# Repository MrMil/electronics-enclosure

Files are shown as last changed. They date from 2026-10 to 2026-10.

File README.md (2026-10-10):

# electronics-enclosure

Parametric 3D-printed enclosures for mains-powered LED controllers. Each enclosure houses a
power supply, a C14 inlet, perfboards and connectors, and is generated from a YAML file of
measurements into ready-to-slice STLs: an open base and a tool-free sliding lid.

<!-- META-DOCS:BEGIN -->
## Documentation

The design of this project, and the reasoning behind it, lives in [`docs/`](docs/README.md) — a
recursive tree that mirrors the system part by part, down to individual behaviours, with every
decision recorded alongside the reason it was made. Start at the hub and navigate down.

These docs are written for LLM coding agents. Design changes are documented in the same commit that
makes them; see [`docs/CONVENTIONS.md`](docs/CONVENTIONS.md).
<!-- META-DOCS:END -->

## Enclosures

| Name | Power supply | Contents | Prints |
|---|---|---|---|
| [`20W`](enclosures/20W/BOM.md) | S-20-5 (5 V 4 A) | C14, 1 perfboard, 2 LED exits in the floor | base + lid on one A1 plate |
| [`100W`](enclosures/100W/BOM.md) | S-100-5 (5 V 20 A) | C14, 1 perfboard, 4 LED exits | base and lid separately |
| [`100W-rj45`](enclosures/100W-rj45/BOM.md) | S-100-5 | as 100W plus an RJ45 bulkhead | base and lid separately |
| [`100W-leds-on-floor`](enclosures/100W-leds-on-floor/BOM.md) | S-100-5 | as 100W, LED exits in the floor | base and lid separately |
| [`100W-masterbox`](enclosures/100W-masterbox/BOM.md) | S-100-5 | C14, ESP32 board, MAX485 board, 3 RJ45, 4 LED exits | base and lid separately, fills the A1 bed |
| [`100W-power-only`](enclosures/100W-power-only/BOM.md) | S-100-5 | C14, 2 XT60 pigtail outputs, no perfboard | base and lid separately |

Each enclosure's `BOM.md` shows renders of it (empty base, base with parts, closed) and lists its
printed parts, bolts and nuts, where supports may be needed, and what to check before printing.

| | Base, no lid | Base with parts | Closed |
|---|---|---|---|
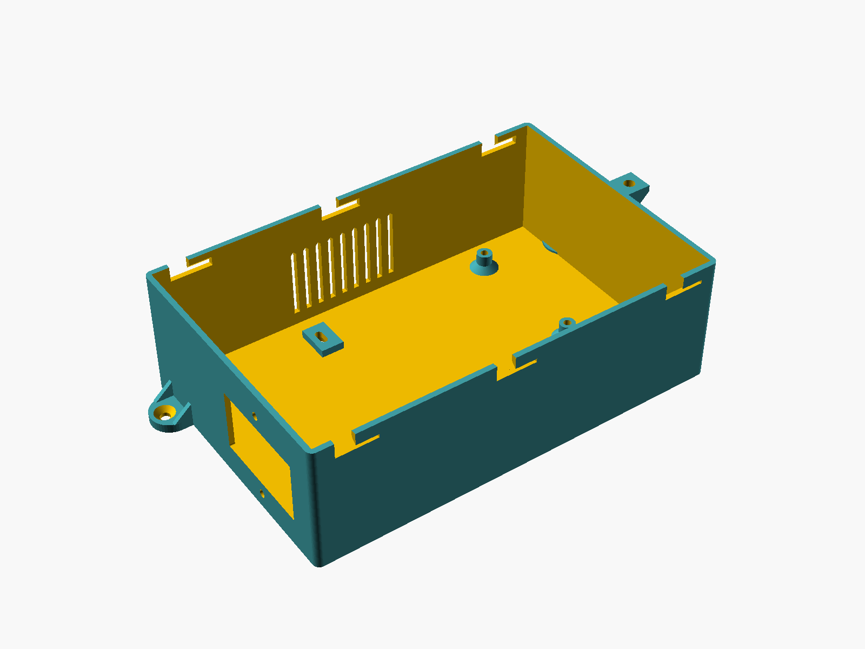
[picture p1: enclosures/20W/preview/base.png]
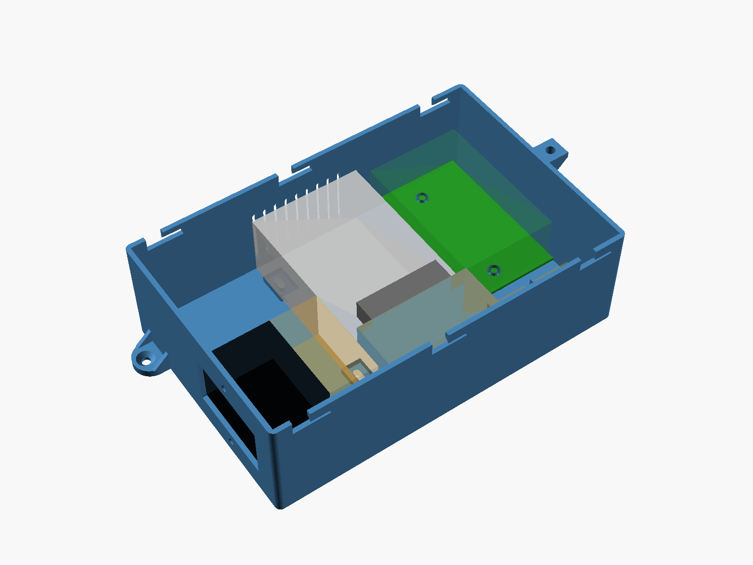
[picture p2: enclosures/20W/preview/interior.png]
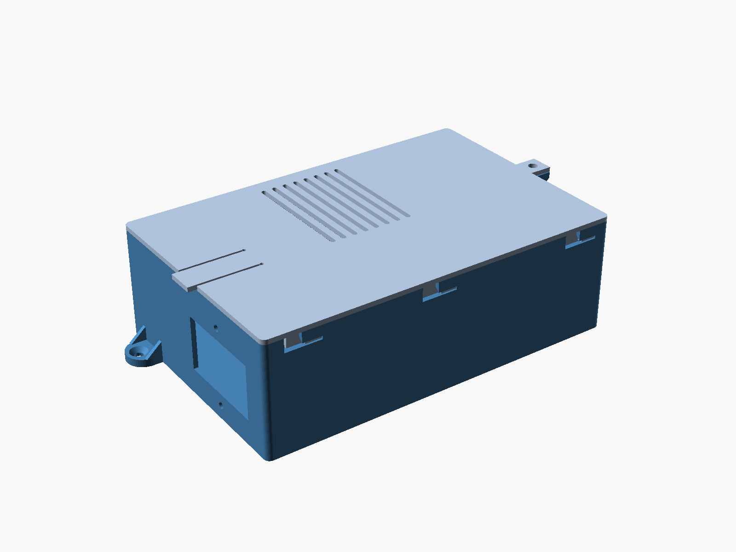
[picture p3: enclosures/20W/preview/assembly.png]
| **20W** |  |  |  |
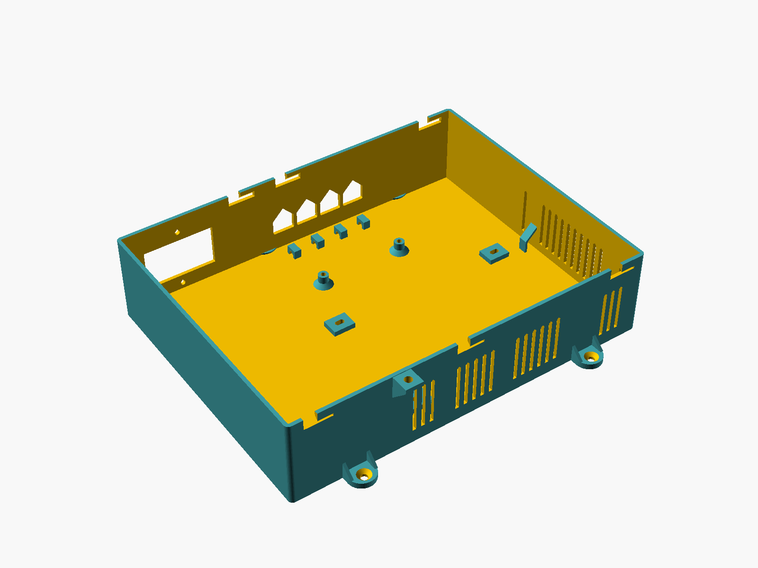
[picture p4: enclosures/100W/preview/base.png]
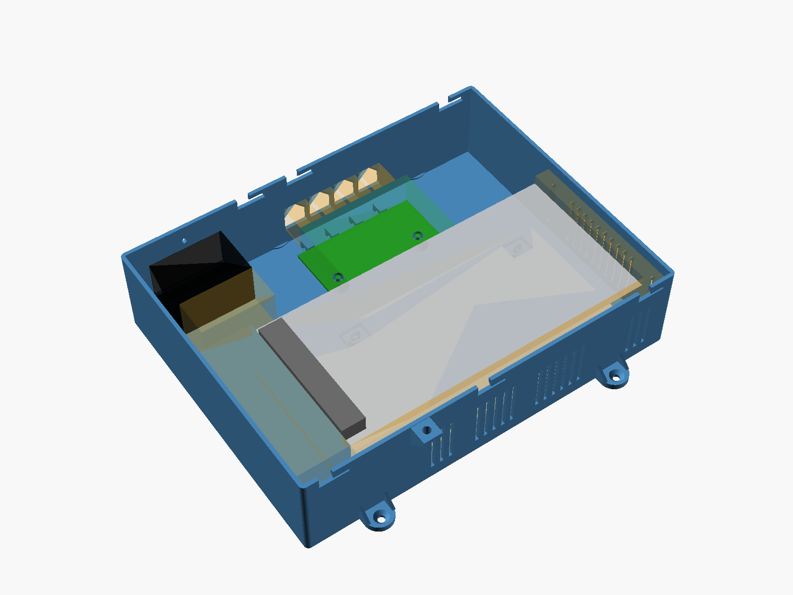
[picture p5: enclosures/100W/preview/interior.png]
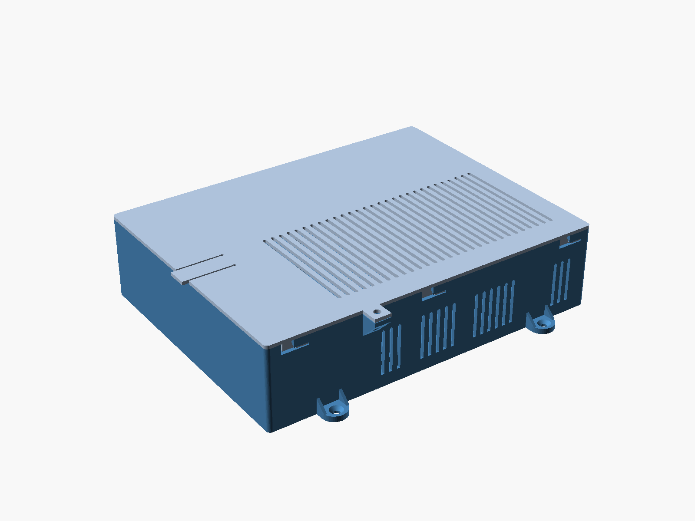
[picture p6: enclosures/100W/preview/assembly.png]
| **100W** |  |  |  |
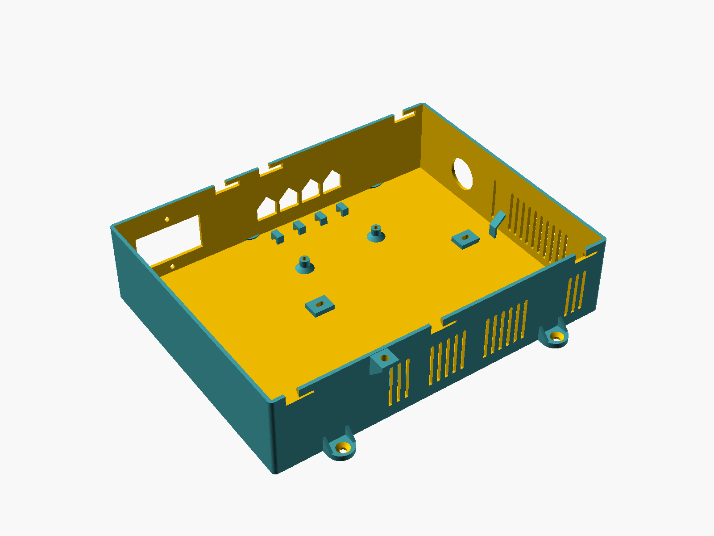
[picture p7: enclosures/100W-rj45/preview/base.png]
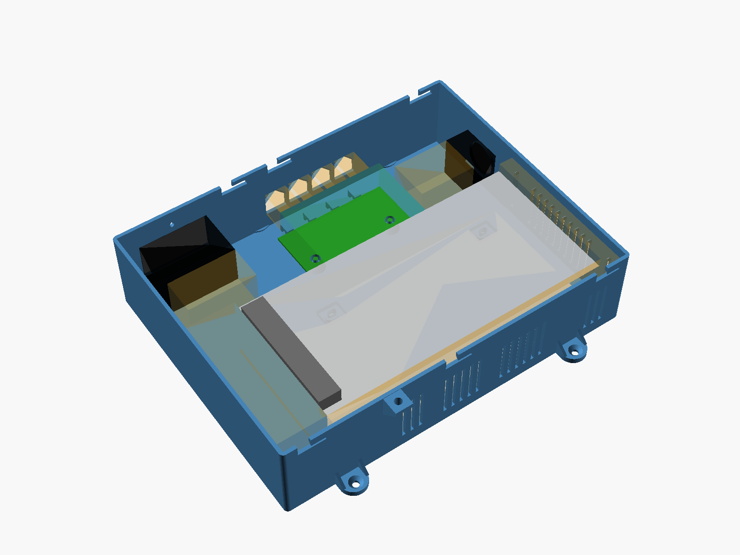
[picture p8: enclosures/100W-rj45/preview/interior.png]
| **100W-rj45** |  |  |  |
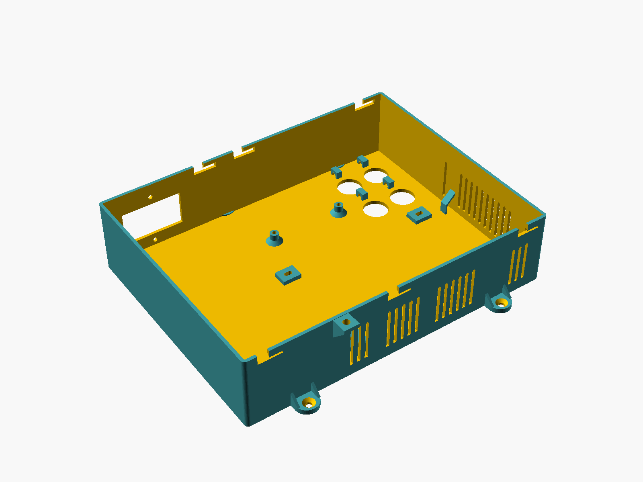
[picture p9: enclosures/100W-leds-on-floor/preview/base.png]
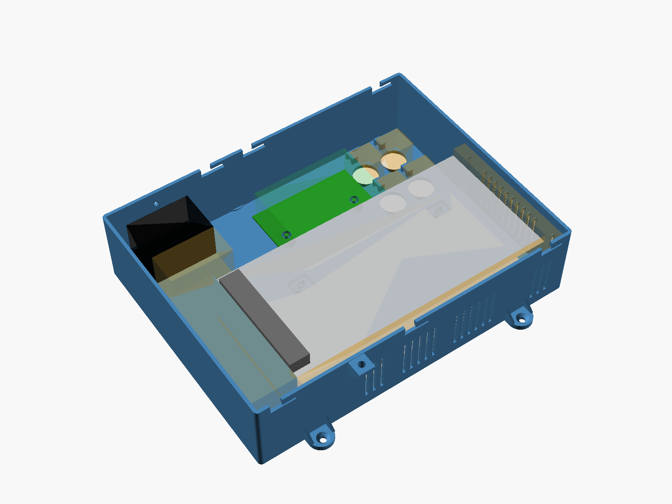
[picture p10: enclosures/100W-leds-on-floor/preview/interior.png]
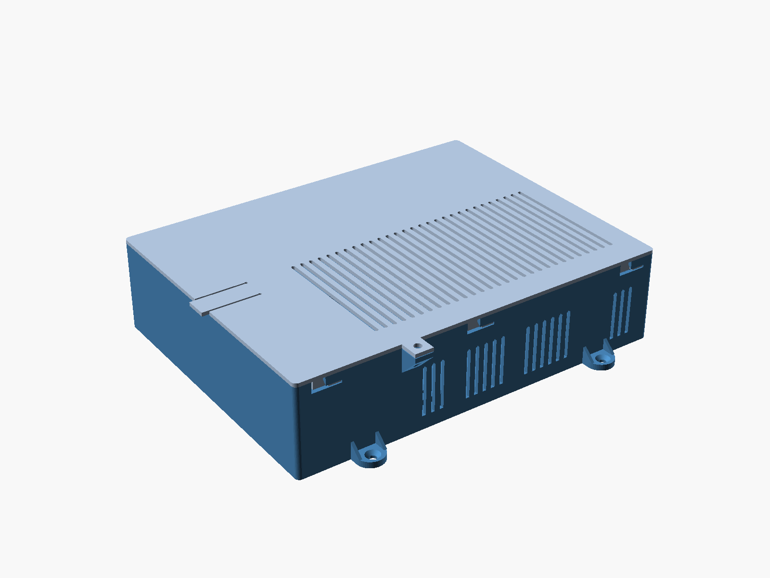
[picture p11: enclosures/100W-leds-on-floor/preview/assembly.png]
| **100W-leds-on-floor** |  |  |  |
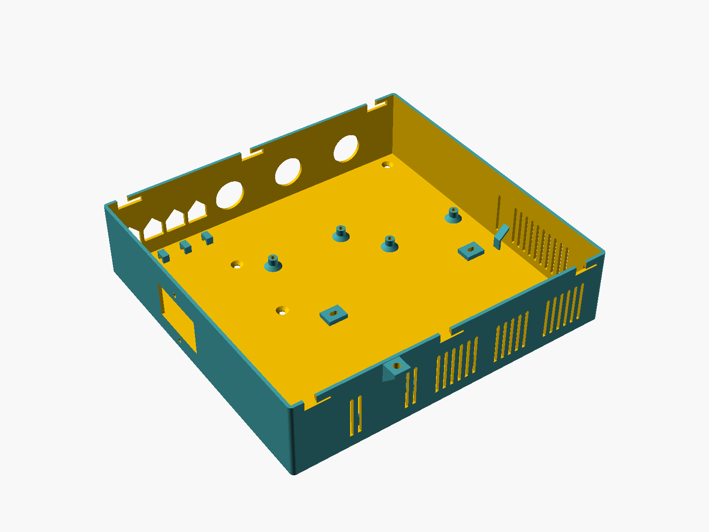
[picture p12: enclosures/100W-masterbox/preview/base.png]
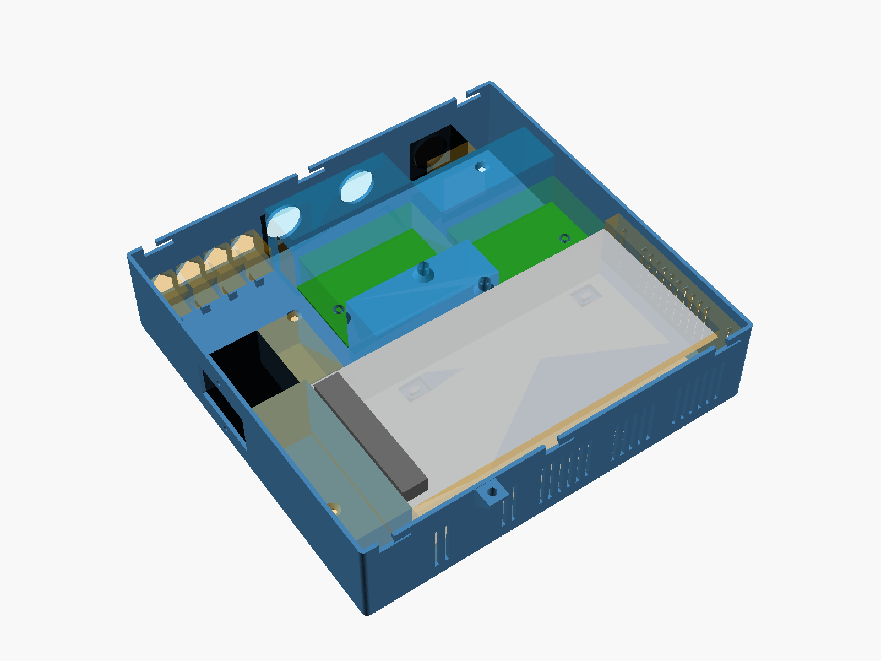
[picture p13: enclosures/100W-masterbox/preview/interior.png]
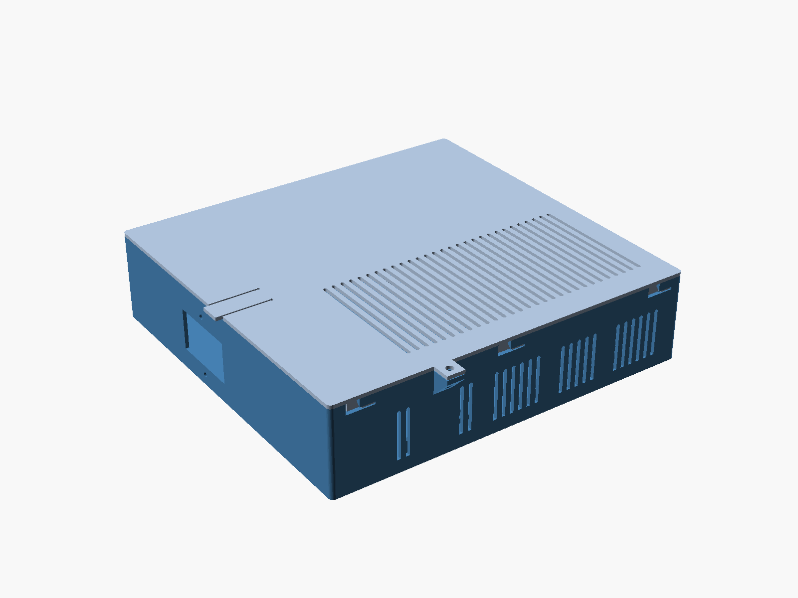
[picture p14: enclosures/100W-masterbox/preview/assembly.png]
| **100W-masterbox** |  |  |  |
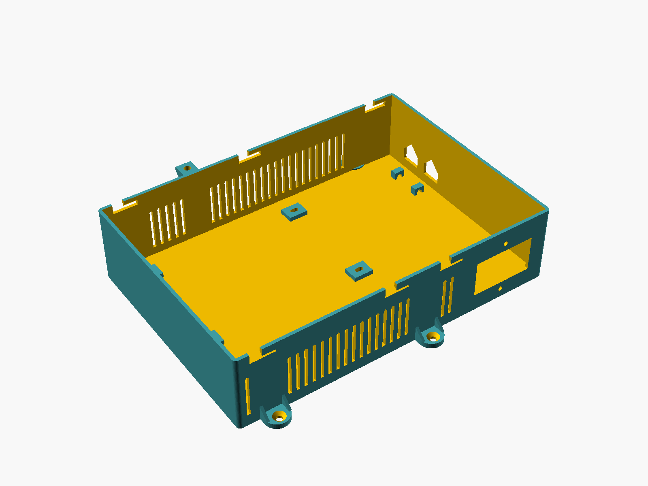
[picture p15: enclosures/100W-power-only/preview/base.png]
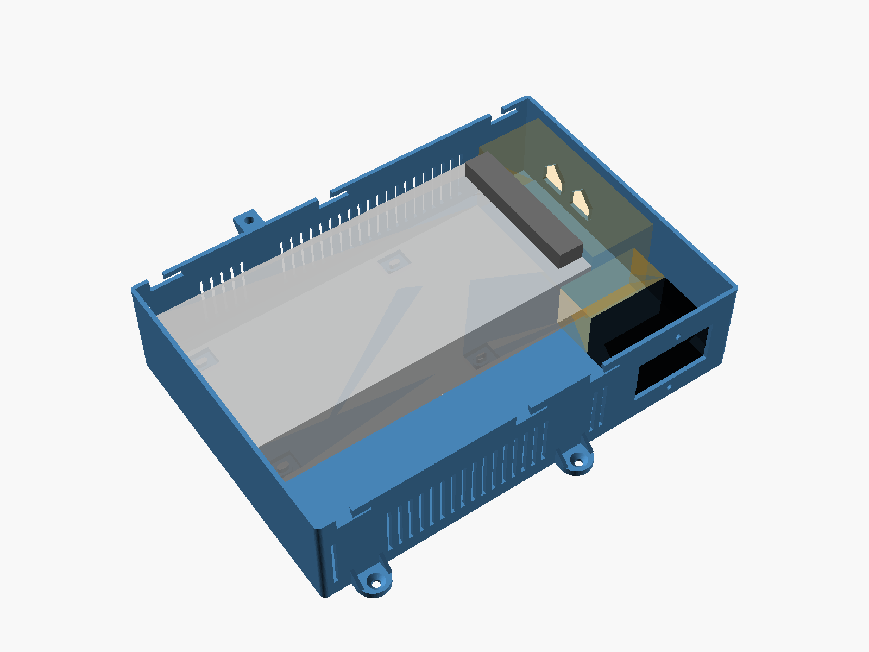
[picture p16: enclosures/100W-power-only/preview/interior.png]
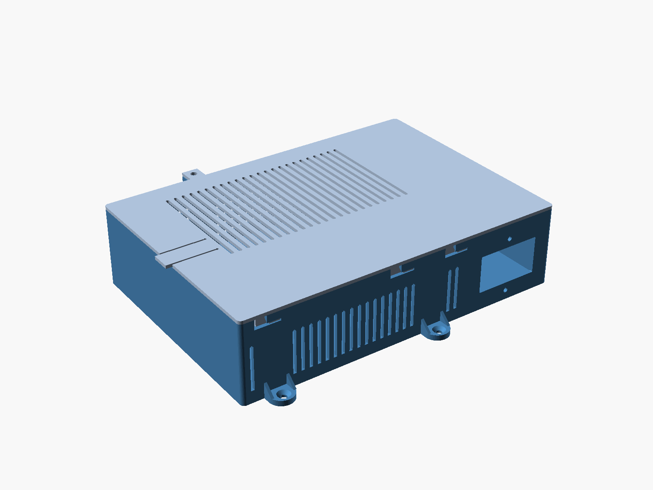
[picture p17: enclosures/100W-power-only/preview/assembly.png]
| **100W-power-only** |  |  |  |

## Quick start

```bash
python3 -m venv .venv && .venv/bin/pip install -r requirements.txt
```

```bash
brew install --cask openscad@snapshot
```

```bash
.venv/bin/python build.py 100W
```

Outputs land in `enclosures/<name>/`:

- `stl/<name>-enclosure-base.stl`, `stl/<name>-enclosure-lid.stl` — already in print orientation;
  `stl/<name>-enclosure-plate.stl` too when both fit on one bed.
- `preview/*.png` — the box closed, open with its parts as coloured blocks, and empty.
- `BOM.md` — hardware, print notes, board-drilling positions for floor wire exits, checks.

`--check` validates a layout without rendering; with no name, every enclosure is built.
`--coupon jst-sm-3pin` writes a small test plate for trying a connector through its slot.

## How a box is put together

- **Power supply** bolts up through the floor into its own M3 threads.
- **Mains and low voltage never cross:** the C14 sits on the supply's AC side; low-voltage wires
  stay on the DC side or run through printed wire loops around the supply's far end.
- **Lid:** drops in 10 mm off-centre, slides shut and clicks. Lift the tab at the edge to open.
  A zip tie through the lock lugs keeps it shut.
- **Hardware:** M3 socket-head bolts and M3 hex nuts only, no heat-set inserts.
- **Print in PETG or ASA**, not PLA: the supply runs warm.

## Layout

| Path | What |
|---|---|
| `enclosures/<name>/enclosure.yaml` | one enclosure: interior size and where each part goes |
| `components/<kind>/<part>.yaml` | measured parts (PSUs, perfboard, panel connectors, pass-throughs), reused across enclosures |
| `config/defaults.yaml` | house style: walls, M3 hardware, lid, vents, mounting, printer bed |
| `enclosure_builder/` | Python: merge, layout, validation, BOM, OpenSCAD driver |
| `scad/enclosure.scad` | geometry library |
| `test-prints/` | small test-fit pieces |
| `docs/` | design decisions and their reasons |

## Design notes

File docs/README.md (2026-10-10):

# Documentation Hub

**Audience: LLM coding agents working in this repository. Not human onboarding material.**
Optimise for a reader with no memory of previous sessions, who can read files fast, and who needs
to know *why* the code is the way it is before changing it.

This tree mirrors the system as a recursive hub-and-spoke: every directory is a part of the system,
its `README.md` indexes what is inside it, and the nesting goes as deep as the system does. Each
page explains its piece and records the reason behind every choice made there. The code is the
source of truth for what happens. These docs are the source of truth for why.

## How to use this tree

1. Start here and navigate down, one index at a time, to the page covering what you are about to change. Never guess paths.
2. **Read every `README.md` on the way down.** Decisions recorded at a level apply to everything beneath it. The reason a leaf behaves as it does may be recorded two levels up.
3. Before finishing work, run the documentation pass in [CONVENTIONS.md](CONVENTIONS.md#the-documentation-pass).

## Design

The system turns measurements of specific hardware into printable enclosures. Each enclosure is a
named directory under `enclosures/` holding its `enclosure.yaml` and the generated STLs. Every
enclosure houses a power supply.

### Decisions

- **The owner's requirements are the root constraints.** Every
  enclosure: houses a PSU and keeps it ventilated; holds a perfboard by its holes (2 for the first
  board, 4 for most); has a C13-cord inlet (a C14 module) in a side wall; has wire exits for LED
  strips (a power-only box, with the PSU's outputs on connectors instead of a board, is the owner's
  call per enclosure: `100W-power-only`, 2026-10-10); may have an RJ45 bulkhead; has a lid that cannot come undone but opens repeatedly
  without tools, bolts or nuts (hardware is fine for assembly, not for opening); leaves room for
  the wires and cables every part has; has parametric holes for fixing it in place; prints with minimal supports; uses as few non-printed
  parts as possible, one bolt size, and no threaded inserts — bolts through printed walls into
  nuts are preferred. Agents must not trade any of these away without asking the owner.
- **One bolt size: M3 socket head everywhere.** The owner asked for a single small bolt size and
  the S-100-5 PSU's own mounting holes are M3, so M3 is the size that needs no adapter. The only
  non-M3 fasteners are the screws that fix the enclosure to its surface (owner's choice, a
  parameter) and the RJ45 coupler's own nut.
- **No threaded inserts, no tapping plastic.** Every M3 joint ends in a metal thread: the PSU's
  own threads, or a hex nut held in a printed pocket or slot. Owner preference; it also means
  threads never wear out with repeated opening.
- **Geometry adapts to standard bolt lengths, not the reverse.** Printed heights (PSU pads,
  standoffs, nut-slot depth) are computed from a chosen standard M3 length, because printed
  dimensions are free and bolt lengths are discrete. The BOM then lists only lengths you can buy.
- **Everything prints without supports**, by fixed print orientation (base floor-down, lid
  top-down) plus the tricks in [enclosure/printability.md](enclosure/printability.md). Owner
  requirement.
- **Find dimensions in manufacturer documentation first; the owner verifies.** The owner would
  rather check a few numbers than take many caliper measurements (and finds some, like flange
  overhangs, hard to measure). Component files record `source:` and `verified: true | datasheet |
  false`. `datasheet` values are listed in the BOM under "Check before printing" with the one
  measurement that confirms them; `false` (guessed) values are build warnings. A guessed number
  can therefore never silently become "known".
- **Units are millimetres; one coordinate frame everywhere** — defined in
  [parameters/README.md](parameters/README.md).
- **Print in PETG or ASA, not PLA.** The PSU case runs warm at full load, and PLA creeps under the
  bolted PSU pads over time. Recorded in every generated BOM.

### YAML → Python → OpenSCAD

**Why.** The person (or agent) creating an enclosure writes measurements; YAML is the easiest
format to write and diff. Layout logic (deriving heights from bolt lengths, generating vents that
avoid other features, checking collisions, writing a BOM) is awkward in OpenSCAD's language and
easy in Python. OpenSCAD is the standard tool in 3D printing for parametric solids, and the
generated `.scad` files can be opened in its GUI for inspection.
**Rejected.** CadQuery: no wheels for the Python in use (3.14) and a heavy OCC dependency. Pure
OpenSCAD with the Customizer: no validation, no BOM, and parameters would live in a format nobody
else reads.
**Constrains.** The SCAD library is geometry-only and knows nothing about specific components;
all component knowledge lives in Python and the component YAML files. Requires an OpenSCAD
snapshot with the manifold backend (2021.01 stable is far too slow for the vent patterns).

## Areas

- [`parameters/`](parameters/README.md) — the YAML inputs: defaults, component library, enclosure definitions, coordinate frame.
- [`enclosure/`](enclosure/README.md) — the printed object: shell, lid closure, PSU and perfboard mounts, wall openings, ventilation, mounting, printability.
- [`pipeline/`](pipeline/README.md) — `build.py`: layout model, validation, SCAD/BOM output and rendering.
- [`enclosures/`](enclosures/README.md) — the concrete, named enclosures and what is still unmeasured in each.

## Files

- [CONVENTIONS.md](CONVENTIONS.md) — the rules for writing and maintaining these docs. Read before adding anything here.

## Invariants

These hold at every depth. If you find one broken, fix it before continuing your task.

- Every directory under `docs/` contains a `README.md` listing every subdirectory and every `.md` file beside it, each with a one-line description.
- Every page and every index links to its parent, carries its breadcrumb path, and links to at least one related page.
- No statement of a design choice appears anywhere in this tree without its reason.
- Every decision is recorded at the lowest level that contains everything it governs.
- No code change ships without the corresponding documentation change in the same commit.

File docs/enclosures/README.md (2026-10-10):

# Enclosures

Path: [docs](../README.md) › **enclosures**
Parent: [../README.md](../README.md)

**Covers:** the concrete, named enclosures in `enclosures/`, the layout decisions specific to
each, and which of their parts are still unmeasured.
**Code:** `enclosures/*/enclosure.yaml`

## Design

### Decisions

- **One page per enclosure, named after it.** Layout choices (which wall the inlet is on, where
  mains and low voltage are separated) belong to one enclosure and must not leak into the feature
  pages, which apply to all of them.
- **LED exits go in a wall unless the owner asks for the floor** (owner, 2026-10-08). Floor
  exits need the mounting board drilled, so they are the owner's call per enclosure: `20W` and
  `100W-leds-on-floor` have them; `100W`, `100W-rj45` and `100W-masterbox` keep theirs in the
  back wall.
  **Changed 2026-10-08:** previously "100W boxes never use the floor", from the owner moving the
  masterbox's exits back into a wall; the owner then asked for a 100W variant with floor exits.
- **Variants of one layout share a page and use `extends`** (`100W-rj45` and
  `100W-leds-on-floor` extend `100W`), so their layout reasoning is written once.
- **Enclosure names are the owner's**, after the PSU's power (`100W`), with a `-<variant>`
  suffix for variants (`100W-rj45`). A new revision with incompatible hole positions gets a new
  name rather than silently replacing STLs someone may already have printed.
  **Changed 2026-10-08:** previously agent-chosen descriptive names (`led-controller-1`).

## Contents

### Pages

- [`20w.md`](20w.md) — `20W`: S-20-5 PSU facing the front, inlet left, perfboard beside it, two round JST-SM LED holes in the floor.
- [`100w-masterbox.md`](100w-masterbox.md) — `100W-masterbox`: bed-filling S-100-5 box, ESP32 board + MAX485 board with side clearance, three RJ45s, four back-wall LED exits.
- [`100w-power-only.md`](100w-power-only.md) — `100W-power-only`: S-100-5 with terminals to the right, C14 in the front wall (sharing it with the lid-lock slots), two XT60 pigtail outputs through the right wall beside the DC terminals; no perfboard.
- [`100w.md`](100w.md) — `100W`, `100W-rj45` and `100W-leds-on-floor`: S-100-5 PSU, DIKAVS perfboard, C14 inlet, four JST-SM LED exits (back wall, or floor), optional RJ45.

## Related

- [../parameters/enclosure_definition.md](../parameters/enclosure_definition.md) — how to write a new one.

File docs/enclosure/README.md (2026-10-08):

# Enclosure

Path: [docs](../README.md) › **enclosure**
Parent: [../README.md](../README.md)

**Covers:** the printed object — two parts, base and lid — and every feature on them. Each page
covers one feature end to end: its component YAML (if any), its placement in Python, and its
geometry in SCAD.
**Code:** `scad/enclosure.scad`, `enclosure_builder/layout.py`, `components/`

## Design

### Decisions

- **Two printed parts: an open-top base and a flat lid.** All components mount to the floor and
  walls of the base, so the lid carries nothing and can be removed without disturbing wiring.
  Rejected: a clamshell split at mid-height — panel parts would straddle the seam, and the PSU
  would have to be mounted to a part that is lifted off.
- **Base prints floor-down, lid prints top-face-down.** Both put their largest flat face on the
  bed, which leaves every hole either vertical or in a vertical wall — the two cases that print
  without supports. See [printability.md](printability.md).
- **The SCAD library only knows generic primitives** (wall rects/rounds/slots, floor bolts,
  standoffs, pads, lock slots and tongues, tabs, tie anchors, lid slots, ghosts). Every feature page below
  describes the Python function that emits them. See the root
  [YAML → Python → OpenSCAD](../README.md#yaml--python--openscad) decision.
- **Every part declares the space its wires need, as a `wiring` keep-out.** PSU terminals,
  panel-part cables and wire exits all get one; wiring zones may meet each other (that is where
  connections are made) but nothing solid may enter them. Shown orange in `interior*.png`.
  **Why:** V1 only reserved space for part bodies, and the owner found the RJ45 had no room for
  its cable and the inlet none for its wires (2026-10-07). A zone is checked by the validator,
  so a later layout cannot quietly crowd it. **Not checked:** that a wire can actually route
  from one zone to another — that remains a layout decision, recorded per enclosure.
- **Mains and low voltage live on opposite sides of the PSU, so their wires never cross.** The
  PSU component says which side of its terminal block is AC (`ac_side`, as seen facing the
  block); panel parts marked `mains: true` must sit on that side of the PSU's centre line, and
  perfboards and other panel parts on the DC side — or on the AC side beyond the mains parts,
  if their wires go round the PSU's far end ([wire_routing.md](wire_routing.md)). The validator
  enforces it. **Why:** owner
  requirement (2026-10-07) after V2 put the inlet on the AC side but the perfboard there too, so
  the DC wires had to cross the mains wires. A box-level rule, not a per-enclosure note, because
  every enclosure has a PSU, an inlet and electronics.
- **Interior corners are sharp, outer corners are rounded** (`box.outer_radius`). Sharp inside
  corners keep the full interior rectangle usable for the lid lip and component keep-outs;
  rounded outside corners only affect looks and handling.

## Contents

### Pages

- [`shell.md`](shell.md) — walls, floor and the shared outline of base and lid.
- [`lid_closure.md`](lid_closure.md) — tool-free drop-and-slide lid: tongues, ledges, detent tab, zip-tie lock.
- [`psu_mount.md`](psu_mount.md) — the PSU component and how it is bolted through the floor.
- [`perfboard_mount.md`](perfboard_mount.md) — perfboard component, standoffs and floor nut pockets.
- [`wall_openings.md`](wall_openings.md) — panel parts (C14 inlet, RJ45), wire exits (holes, JST pass-throughs, floor exits), zip-tie anchors.
- [`wire_routing.md`](wire_routing.md) — low-voltage route round the PSU's far end, printed wire loops.
- [`ventilation.md`](ventilation.md) — wall slots and lid slots for the PSU.
- [`mounting.md`](mounting.md) — tabs or floor holes for fixing the enclosure in place.
- [`printability.md`](printability.md) — print orientation, teardrops, bridged pockets.

## Related

- [../pipeline/validation.md](../pipeline/validation.md) — checks that these features do not collide.
- [../parameters/defaults.md](../parameters/defaults.md) — default values for these features.

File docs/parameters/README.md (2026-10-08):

# Parameters

Path: [docs](../README.md) › **parameters**
Parent: [../README.md](../README.md)

**Covers:** the YAML inputs and how they combine into one parameter tree per enclosure; the
coordinate frame every other part uses.
**Code:** `config/defaults.yaml`, `components/`, `enclosures/*/enclosure.yaml`, `enclosure_builder/config.py`

## Design

### Decisions

- **Layers, merged in order: `config/defaults.yaml` ← the enclosure it `extends:` (if any) ←
  `enclosures/<name>/enclosure.yaml` ← per-instance `override:`.** `extends` exists because the
  owner needs the same enclosure with and without an RJ45; a variant states only its
  differences, so a layout fix in the base enclosure reaches both. Defaults hold the house
  style (wall thickness, M3 dimensions, lid design) so an enclosure file only states what is
  specific to it. Mappings merge key by key;
  lists replace wholesale, because merging lists element-wise (e.g. hole lists) would silently mix
  two parts' geometry.
- **Parts are referenced by name from a component library** (`components/<kind>/<part>.yaml`)
  rather than dimensioned inline. A measured part is measured once and reused by every enclosure;
  an enclosure can still correct one value through `override:` without forking the file.
  See [component_library.md](component_library.md).
- **`psu:` is mandatory.** The owner requires every enclosure to house a power supply; making it
  required catches a forgotten PSU at load time instead of producing an empty box.
- **The enclosure's `name:` must equal its directory name**, so a copied directory with a stale
  name fails loudly instead of overwriting another enclosure's outputs.

### Coordinate frame

Interior corner at the origin. `x` runs along the length (left wall → right wall), `y` across
(front wall → back wall), `z` up, with `z = 0` the top surface of the floor. Walls, floor
and tabs lie outside the interior box `[0,L] × [0,W] × [0,H]`.

Wall features are placed with `(wall, u, z)`: `wall` ∈ front/back/left/right, `u` measured along
the wall from its end with the smaller `x` (front/back) or smaller `y` (left/right).

**Why.** Interior coordinates are what a person measures from ("PSU 4 mm off the front wall"), and
they stay valid when wall thickness changes. `u` follows the global axes rather than "left to right
as seen from outside" so that one number means the same position on the inside and outside faces
and no wall needs a mirrored convention.
**Constrains.** Seen from outside, `u` grows to the left on the back and left walls. Documented in
every `enclosure.yaml` header so nobody "fixes" it.

## Contents

### Pages

- [`defaults.md`](defaults.md) — the house-style values in `config/defaults.yaml` and why each was chosen.
- [`component_library.md`](component_library.md) — the `components/` directory: kinds, schema, `verified` flag.
- [`enclosure_definition.md`](enclosure_definition.md) — the schema of `enclosures/<name>/enclosure.yaml`.

## Related

- [../pipeline/README.md](../pipeline/README.md) — consumes the merged tree.
- [../enclosure/README.md](../enclosure/README.md) — what each parameter turns into.

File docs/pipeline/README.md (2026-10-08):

# Pipeline

Path: [docs](../README.md) › **pipeline**
Parent: [../README.md](../README.md)

**Covers:** `build.py` — from a merged parameter tree to STLs, previews and a BOM.
**Code:** `build.py`, `enclosure_builder/`

## Design

Flow per enclosure: `config.load_enclosure` → `layout.build_model` → `validate.validate` →
`emit.write_scad` + `emit.write_bom` → `render.render_stl` / `render_png`.

### Decisions

- **Validation runs before anything is written.** A layout error must never leave STLs on disk
  that look current; the previous good outputs stay until the layout is fixed.
- **`--check` writes SCAD and BOM but no STLs** — a fast loop (well under a second) for an agent
  iterating on positions; STL + previews take ~10 s.
- **Generated files are kept in the repository next to `enclosure.yaml`**, not git-ignored
  (`build/*.scad`, `stl/`, `preview/`, `BOM.md`). The owner asked for the STLs to live in the
  enclosure's directory, and the previews and BOM let a reader review an enclosure without
  installing OpenSCAD. Every generated text file says GENERATED in its header.
- **Python dependencies are only PyYAML**, installed in `.venv` (`pip install -r
  requirements.txt`). OpenSCAD is an external program found on `PATH` or in `/Applications`.

## Contents

### Pages

- [`layout_model.md`](layout_model.md) — `layout.py`: the Model, primitives, keep-outs, wall footprints, bolt-length picking.
- [`validation.md`](validation.md) — `validate.py`: what is checked and why.
- [`output.md`](output.md) — `emit.py`, `render.py`, `cli.py`: generated SCAD, BOM, STL and PNG rendering.

## Related

- [../parameters/README.md](../parameters/README.md) — the inputs.
- [../enclosure/README.md](../enclosure/README.md) — what each placement function produces.

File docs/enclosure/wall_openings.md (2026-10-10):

# Wall openings

Path: [docs](../README.md) › [enclosure](README.md) › **wall_openings**
Parent: [README.md](README.md)
**Code:** `components/panel/`, `components/passthrough/`, `enclosure_builder/layout.py` (`place_panel_parts`, `place_wire_holes`), `scad/enclosure.scad` (`wall_cutters`, `FLOOR_SLOTS`, `tie_anchor`)
**Covers:** everything wires or connectors pass through, except vents: panel parts (C14 inlet,
RJ45 bulkhead) and wire exits (round holes or connector pass-through slots in a wall; round holes
in the floor).

## What it does

A **panel part** (`components/panel/`) is a cutout (`rect` or `round`), optional M3 flange bolts
relative to the cutout centre, a `flange` footprint on the outside face, an `inside` solid body
keep-out, a `cable` wiring zone behind the body, optional `max_panel_t`, and `mains: true` for
parts carrying mains (they must sit on the PSU's AC side, see [README.md](README.md)).

A **wire exit** (`wire_holes[]`) is either a round hole (`d`) or a library pass-through
(`part:` from `components/passthrough/`: a rounded `slot` for walls, a `round` hole with its
`drill` size for the floor), on a wall (`wall, u, z`) or in the floor (`wall: floor, at: [x, y]`;
`rotate` turns a slot, and on a round hole only picks where the default zip-tie anchor goes).
Each gets a wiring zone `inside_depth` deep and, by default, a printed zip-tie anchor.

## Decisions

- **Panel parts declare their cable space separately from their body.** The body is solid; the
  cable zone is `wiring` and may meet other wiring zones (C14 wires meeting the PSU terminal
  zone) but no solid part. Added because V1 placed the RJ45 coupler with no room for its patch
  cable and the inlet with no room for its wires (owner feedback 2026-10-07).
- **C14: measured by the owner.** 27 × 47 body (cut 27.5 × 47.5), M3 through 3.6 mm flange holes
  39.8 mm apart, flange 50.4 × 69 × 2.6, wires to ~60 mm behind the panel. Body depth 35 mm is an
  estimate inside that 60. Nut inside, head outside (owner's preferred joint).
- **Flange-bolt nuts are checked**: each nut's footprint on the inside face must clear the floor
  and the lid lip by 0.5 mm (`edge_margin`; a nut needs room to sit and turn, not wall material
  around it). Added after a lying-down C14 put its nuts into the floor and the lip.
- **C14 orientation is per enclosure.** Upright, its 69 mm flange sets the box height; with
  `rotate: 90` it needs ~50 mm. 100W uses 90 so the box can be PSU-height.
- **RJ45: measured by the owner.** 23.4 mm thread (cut 24.0), 29 mm nut, 18 mm behind the panel.
  The cable zone (60 mm) is plug ~22 + boot ~15 + a Cat6A bend. Outside flange not measured;
  assumed ≤ the nut.
- **LED exits are pass-through slots for JST SM 3-pin connectors**, so the owner can solder
  pigtails to the perfboard outside the box and feed them out (owner request). Slot 15.6 × 10.2:
  the full outside envelope of either 3-pin housing from JST's drawings — plug SMP-03V-BC 8 × 7.4
  plus latch flaps standing ~3.2 mm out each side (14.6 across the pins), receptacle SMR-03V-B
  10.5 × 7.5 plus a 1.7 mm lock bump (9.2 thick) — + 0.5 mm per side, so a connector passes
  without squeezing its flaps. Envelopes for connectors passing through holes always include
  latches, flaps and bumps, never just the body.
  **Changed 2026-10-08:** was 11.5 × 8.5, from the receptacle's body only; the owner printed the
  20W and the connectors did not fit. `build.py --coupon jst-sm-3pin` prints a test plate.
  Wiring zone 20 mm: the pigtails are fed
  out before the board is screwed down, so afterwards only wire stays inside and needs room to
  bend. (Was 30 mm, sized for the 18.2 mm housing; that made the box too deep for the bed.)
- **XT60 power outputs are female pigtails through a 16.5 × 9.1 slot** (`xt60-f`, owner
  2026-10-10, for `100W-power-only`): the bare lead ends go straight into the PSU's screw
  terminals, so nothing is soldered in the box, and the slot sits near the DC terminals so the
  pigtail's own leads reach. Slot = the Amass XT60-F drawing's 15.5 × 8.1 mating face (chamfered
  corners included; side ribs and the solder cups under heat-shrink stay inside it; the female
  has no latch) + 0.5 mm per side, by the same full-envelope rule as the JST slot, so the
  connector can pass either way. **Rejected:** a flanged panel-mount XT60 (XT60E-F): the owner
  has pigtails and would need short wires soldered to its cups. **Unknown:** the XT60H's
  snap-on sheath size — Amass publishes no drawing; `build.py --coupon xt60-f` tests a real one.
- **Pass-throughs are a library kind, not inline sizes**, because the same connector will be used
  on every LED enclosure and its size came from a datasheet that should be cited once.
- **Floor exits take `anchor_at: [dx, dy]`** to move the zip-tie anchor when the default spot
  (just behind the hole; to its right with `rotate: 90`) is under a part, as in the 20W.
- **Wire exits can be in the floor** (owner's option 3). Floor exits are rejected if they lie
  under a solid keep-out or within `feature_margin` of a wall — a hole tangent to a wall leaves
  no floor between them, and the check was needed once floor holes grew to 20 mm. The surface
  below must have matching holes (the owner drills the wooden mounting board); the BOM's
  "Drilling the mounting surface" gives their positions from a mounting hole and the drill size.
- **Floor exits are round, and the board is drilled straight through them** (owner,
  2026-10-08): with the enclosure screwed down and empty, the owner drills the board through each
  hole, so the board's holes line up without measuring. A slot cannot be drilled through without
  a bit bigger than its width cutting the plastic. Wall exits stay slots: nothing is drilled
  through them, and a 20 mm round hole with its 45° point would take far more wall.
  **JST SM: 20 mm printed hole, 18 mm drill.** The connector needs a circle of ~15.2 mm (the
  plug's latch-flap tips) and at most 16.4 mm (the diagonal of the plug's 14.6 × 7.4 envelope);
  18 mm is a common spade, Forstner and step-drill size and clears that by 0.8 mm a side. The
  printed hole is 2 mm bigger than the bit so a hand-held bit that wanders 1 mm still does not
  touch the plastic (FDM holes also print a little small). The part's `round` hole is used in
  the floor automatically rather than by a per-hole switch, because every floor exit goes
  through the board under the box.
  **Changed 2026-10-08:** floor exits were the same 15.6 × 10.2 slot as wall exits, with the
  BOM giving a drill size covering its diagonal; the owner could not drill the board through
  the slot without damaging it.
- **Every opening has a 45° pointed top**, full on wire exits; on panel parts only when the whole
  point is hidden by the flange, otherwise none. Wall-feature extents include the roof, so the validator spaces it. See
  [printability.md](printability.md).
- **Wall pass-throughs accept `rotate: 90`** (slot stood on end), for walls where a narrower,
  taller opening fits better.
- **Zip-tie anchors next to each exit** so a tug outside never reaches the solder joints or the
  PSU terminals.
- **RJ45 has no M3 bolts** — it clamps with its own nut.

## Gotchas

- JST SM is rated 3 A per contact. Four exits carry at most 12 A of the PSU's 20 A; longer strips
  need separate power injection, not more current through these connectors.
- JST also documents panel-mounting the SM plug in a 0.5–2.0 mm panel; the 2.4 mm wall would need
  `max_panel_t`-style thinning. Not used: the owner wants the connector to pass through.

## Related

- [README.md](README.md) — wiring zones.
- [../pipeline/validation.md](../pipeline/validation.md) — wall-feature and floor-exit checks.
- [ventilation.md](ventilation.md) — vents fill the wall area these features leave free.

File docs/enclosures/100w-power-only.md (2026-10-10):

# 100W-power-only

Path: [docs](../README.md) › [enclosures](README.md) › **100w-power-only**
Parent: [README.md](README.md)
**Code:** `enclosures/100W-power-only/enclosure.yaml`, `components/passthrough/xt60-f.yaml`
**Covers:** the S-100-5 box with no electronics, just the inlet and two XT60 outputs: layout
decisions and what the owner should still check.

## What it does

Interior 242 × 168 × 55 mm; base prints at 246.8 × 200.8 × 58, lid at 250.8 × 184.8 × 9.4
(separate plates). Front to back: the C14 lying down in the front wall toward the right, the
S-100-5 running along the length with its terminals facing the right wall (40 mm of terminal
space), 10 mm of air to the back wall. Two XT60 female pigtails leave through slots in the right
wall straight in front of the DC terminals; their bare leads go into the PSU's −V/+V screws.
Slide-lock lid with the zip-tie lock on the back wall; four mounting tabs on the long walls.

## Decisions

- **Outputs are XT60 female pigtails through wall slots, 10 cm leads** (owner, 2026-10-10:
  "pigtails out a slot", rather than a flanged panel-mount XT60). The owner does not want to
  solder extension wires onto them, so the exits must be close enough to the DC terminals for
  the leads to reach. Female on the supply side, because its contacts are shrouded and a live
  output is never exposed.
- **Layout is the 20W's ([20w.md](20w.md)), turned 90° so the PSU runs along x: terminals to
  the right, inlet in the front wall.** Facing the terminals from the right, AC (L, N, FG) is on
  the left (front), toward the inlet, and DC on the right (back), so the inlet's wires and the
  XT60 leads meet the block from opposite ends of it.
  **Rejected:** the 100W arrangement (inlet in a long wall behind the terminal end) — the
  inlet's 60 mm of body and wires then has to sit beyond the PSU's side, making the box over
  158 wide (98 + 60) *and* ~240 long. The upright inlet (rotate 0) beside the terminal space —
  its 35 mm body may not enter the terminal space, so the PSU still starts 35 in, and the box
  grows to 66 tall: 143 × 244 × 66 against 168 × 242 × 55, no smaller, taller, and unlike the
  other 100W boxes.
- **Turned so the inlet shares a wall with the lid-lock slots** (owner, 2026-10-10): the
  base needed supports on three sides. The build flags only the inlet's flat-topped cutout;
  the other two are taken to be the walls carrying the lid-lock slots (the lid slides along x,
  so they are always the front and back) — an inference from "three sides" and the fix the
  owner asked for, not confirmed. With the inlet in the front wall only the
  front and back need supports. The lid slides along the PSU instead of across it, which is what
  the owner asked for as "rotate the lid"; the builder only slides lids along x, so the layout
  was turned instead.
  **Changed 2026-10-10:** was 168 × 242 with the terminals to the front and the inlet in the
  left wall.
- **XT60 slots at u = 118 and 142, z = 12, in the right wall**: in front of the DC terminals,
  which are estimated at y ≈ 109–138 (S-100F block of 7, ~9.5 mm pitch, centred on the PSU at
  y 60–158; FG ≈ 99.5). Each XT60 takes one −V and one +V terminal (the PSU has two of each), so
  each terminal carries one output's current. Low, so the leads run along the floor through
  their zip-tie anchors (12 mm in) and then rise to the screws.
  **Lead budget:** ~2.4 wall + ~15 to the anchor + ~56 up to a screw (x ≈ 195, z ≈ 46) + ~7
  stripped end ≈ 80–85 mm of the 100, with the connector body against the outside of the wall.
- **Terminal space 40 mm, the library value.** The lid (242 + 4.8 + 4 finger pull = 250.8)
  still fits the 254 mm usable bed with 40, so nothing forces it smaller; 40 also covers the
  inlet's body (x 182–230) reaching past the terminal end.
- **PSU at y = 60** = inlet body (35) + its wire zone (25), as in 20W. **10 mm air gap to the
  back wall, 3 mm behind the far end** (left wall): the back gap feeds the back-wall vents along
  the PSU's DC side; the far end is closed sheet metal.
- **Zip-tie lock on the back wall at u = 70, between the left and middle lid tongues** (at
  u = 121 it hit the middle tongue). **Tabs on the front/back walls (front u = 22, 142; back
  u = 22, 212)**. On the left or right walls either would add 12 mm to the 246.8 mm length and
  push base or lid past the bed. The front tab at 142 clears the inlet flange (u 171.5–240.5).
- **The front-right lid tongue sits at u = 165, not 232** (auto-shifted): the lying inlet's
  flange reaches up into the lock zone, as in 100W.
- **Vents in both long walls** (back u 4–200, front u 4–166, z 6–38) plus lid slots over the
  PSU. The front wall's free strip (y 0–60 beside the inlet) gives the AC side an intake too.
  Neither short wall: the right holds the terminal wiring and the XT60s, the left is 3 mm from
  the PSU's closed end.
- **No perfboard** (owner, 2026-10-10: "power only") — the root "every box holds a perfboard"
  requirement is the owner's default, not a rule for this box ([../README.md](../README.md)).

## Still to check (from datasheets, not measured)

- S-100-5 bottom holes — as in [100w.md](100w.md).
- The XT60 on the pigtail (with its heat-shrink, or an XT60H snap-on sheath) passes the
  16.5 × 9.1 mm slot: print `test-prints/xt60-f-coupon.stl` (the slot is sized from the bare
  XT60-F drawing; the XT60H sheath is not documented).
- The leads are ~10 cm from the back of the connector to the bare end and fit the PSU's
  terminal screws (12 AWG is common on XT60 pigtails).

## Gotchas

- Feed the bare lead ends in from outside through the slots, then zip-tie each pair to its
  anchor before screwing them down: a tug on the XT60 must land on the anchor, not on the
  terminal screws.
- The validator does not apply the mains/low-voltage side rule to wire exits (only to panel
  parts and perfboards); the XT60s are on the DC side by this layout, not by a check.
- Each XT60 is rated 30 A; the PSU gives 20 A in total.

## Related

- [20w.md](20w.md) — the same layout with the S-20-5; inlet position and nut-height reasoning.
- [../enclosure/wall_openings.md](../enclosure/wall_openings.md) — the XT60 slot size and why.
- [../enclosure/psu_mount.md](../enclosure/psu_mount.md) — terminal order and the PSU's local frame.

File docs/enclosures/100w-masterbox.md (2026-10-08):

# 100W-masterbox

Path: [docs](../README.md) › [enclosures](README.md) › **100w-masterbox**
Parent: [README.md](README.md)
**Code:** `enclosures/100W-masterbox/enclosure.yaml`
**Covers:** the bed-filling S-100-5 enclosure for an ESP32 driving 6 MAX485 RS485 transmitters,
two per RJ45 output, with three RJ45 outputs and four LED exits.

## What it does

Interior 244 × 232 × 55 mm; base prints at 248.8 × 248.8 × 58 (+5 mm of support room outside
the left and back walls), lid at 252.8 × 248.8 × 9.4. The S-100-5 runs along the front with its
terminals to the left; low-voltage wires go through printed loops in a 10 mm front channel and
round the PSU's right end, as in [100w.md](100w.md). Behind the PSU:

- **C14** lying down in the left wall, directly behind the PSU's L/N/FG terminals.
- **MAX485 board** (6 modules), long side along the box, 30 mm free on both long sides for the
  modules that overhang them. Two RJ45s in the back wall inside its rear strip.
- **ESP32 board** beside it, 30 mm free behind its long side for the USB-C debug cable; the third
  RJ45 in the back wall behind that.
- **Four JST-SM LED exits** in the back wall left of the RJ45s, behind the C14.

Slide-lock lid, zip-tie lug on the front wall, four countersunk floor screws.

## Decisions

- **What the boards hold sets their clearance** (owner, 2026-10-08): the MAX485 modules are long
  and overhang both long sides of their board — 3 cm each side is enough; the ESP32 needs room on
  one long side for a USB-C cable. Each RJ45 carries the RS485 outputs of two MAX485s (two data
  pairs and a ground pair), so the RJ45s sit at the MAX485 board's rear strip.
  **Changed 2026-10-08:** earlier versions used two identical boards with 5/3 cm long-side
  clearance, then 4 cm of USB-C room at the short ends; neither matched what is on the boards.
  **Changed 2026-10-09:** the board holds 6 MAX485 modules, two per RJ45 (owner correction;
  earlier pages said 8). The board, its 3 cm strips and the three RJ45s are unchanged — the
  module count never set any dimension.
- **C14 in the left wall right behind the AC terminals, not in the back wall.** Its wires run
  ~10 mm to the terminals, so the mains region is the left-front corner only; the floor behind it
  (x 0–80, y 179–232) is usable; the LED exits' wiring room is there. With the C14 in the back wall the whole
  left column in front of it was mains wiring path — the "huge gap in front of the C13".
- **Boards side by side, both long side along x:** 81 + 81 mm fills the 163 mm between the mains
  separation (x 81) and the right wall; the MAX485 board's 30 + 55 + 30 mm fits the back band's
  121 mm depth.
- **LED exits in the back wall at u = 15–66, z = 17**: the owner wants this box's LED exits in a
  wall, not the floor (see [README.md](README.md)); this stretch is ~50 mm from the mains wiring and left of the RJ45s.
  **Changed 2026-10-08:** briefly in the floor; the owner wants them in the walls.
- **RJ45s behind the MAX485 board get 36 mm of cable room** (library 60): enough for the plug and
  boot, then the cable turns along the 30 mm clearance strip. The one behind the ESP32 keeps 60.
- **Support room 5 mm outside the left (C14) and back (RJ45) walls.** The right wall has only
  pointed vents.
- **Zip-tie lug on the front wall at u = 70**; on a short wall it would push the length past the bed.
- **Length 244 = 35 terminal space (library 40) + 199 PSU + 10 loop channel**, set by the lid
  (+4 finger pull). **Width 232**, set by the base (+12 lug, +5 support room).
- **Floor screws:** tabs would push the base past the bed on either axis.

## Gotchas

- Bed fit: 0.2 mm spare on the base, 1.2 mm on the lid (inside the 2 mm bed margin). Any growth
  needs a shorter `lid.tab_pull`, less support room, or a bigger printer.
- Base and lid do not fit one plate; print them separately.
- Four JST-SM exits carry at most 12 A (3 A per contact) of the PSU's 20 A.

## Related

- [100w.md](100w.md) — the layout this extends.
- [../enclosure/wire_routing.md](../enclosure/wire_routing.md) — the low-voltage route and the separation rule.
- [../enclosure/perfboard_mount.md](../enclosure/perfboard_mount.md) — perfboard clearance zones.

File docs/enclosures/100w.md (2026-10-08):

# 100W (and -rj45, -leds-on-floor)

Path: [docs](../README.md) › [enclosures](README.md) › **100w**
Parent: [README.md](README.md)
**Code:** `enclosures/100W/enclosure.yaml`, `enclosures/100W-rj45/enclosure.yaml`, `enclosures/100W-leds-on-floor/enclosure.yaml`
**Covers:** the first enclosure in its three variants: layout decisions and what the owner should
still check.

## What it does

Interior 244 × 186 × 55 mm; base prints at 248.8 × 218.8 × 58, lid at 252.8 × 202.8 × 9.4
(A1 bed 256 with a 2 mm margin; the lid has 1.2 mm to spare in length). Across the width:

- **Front:** a 10 mm channel with four printed wire loops on the front wall, along the PSU's DC side.
- **Middle:** the S-100-5, terminals toward the left wall (35 mm of terminal space).
- **Back band (AC side):** the C14 lying down in the back wall right behind the L/N/FG
  terminals; the perfboard further right; four JST-SM slots in the back wall beside it. In
  `-rj45`, the RJ45 in the right wall level with the perfboard. In `-leds-on-floor`, no slots in
  the back wall: four round JST-SM holes in the floor right of the perfboard instead.

Low-voltage wires go from the DC terminals into the front channel, along the PSU, round its right
end (two more loops) and into the back band to the perfboard. Tool-free slide-lock lid with a
zip-tie lock on the front wall; four mounting tabs.

## Decisions

- **Inlet and perfboard share the back (AC-side) long wall; low voltage goes round the far end.**
  Owner design (2026-10-07), replacing a centred PSU with a 60 mm mains band that was mostly
  empty: width 239 → 186, and the tabs fit again. Inlet wires reach the AC terminals directly;
  DC wires never pass the terminal end on the AC side
  ([../enclosure/wire_routing.md](../enclosure/wire_routing.md)). The perfboard starts 39 mm
  beyond the inlet (the rule needs 20).
  **Changed 2026-10-07:** previously the PSU sat in the middle with the inlet behind it and the
  perfboard in front, because the rule only allowed low voltage on the DC side.
- **Terminal space 35 mm (library default 40).** The inlet's wires now arrive from behind rather
  than the side; 40 would push the lid past the bed. 35 fits ferrules and a 14 AWG bend.
- **Front and far-end channels 10 mm** = 8.6 mm wall loop + 1 mm; the front one doubles as the air
  path past the PSU's front face to the front-wall vents. The 2 mm saved when the loops shrank
  went to the terminal space (length is bed-limited) and to a narrower box.
- **Height 55 mm, set by the inlet's flange nuts.** Lying down (`rotate: 90`, flange 50 mm tall
  instead of 69) the C14's two bolts are stacked 39.8 mm apart; their nuts must clear the floor
  and the lid lip, which needs 55 (inlet at z = 24). The PSU alone would allow ~50: it sits at
  41.5 on its pads, leaving 13.5 mm of air under the lid vents.
  **Changed 2026-10-08:** was 52 with the inlet at z = 22.2, which put the lower nut below the
  floor and the upper one into the lid lip; the validator did not check nuts then.
- **C14 at u = 37 on the back wall**, the closest its 69 mm flange gets to the corner; its rear
  faces the terminal space.
- **Zip-tie lock on the front wall at u = 70**, between the front-left and middle tongues, for
  Midburn ([../enclosure/lid_closure.md](../enclosure/lid_closure.md)). Front, so it is on the
  low-voltage side and reachable when the box sits against a wall by its back.
- **Back-wall tongue at u = 88, not 22**: the inlet flange reaches the lock zone (auto-shifted).
- **Tabs: front at u = 40 and 204, back at u = 100 and 204** — the back-left tab would hit the
  inlet flange.
- **Vents along the front channel and the right wall beside the PSU's end**, plus lid slots over
  the PSU.
- **Two enclosures, one layout.** `-rj45` `extends` the base; the base keeps the RJ45's 60 mm
  cable zone free (perfboard ends at x = 181, zone starts at 184). RJ45 at u = 138.5, level with
  the perfboard's centre.
- **`-leds-on-floor`: the four LED exits as a 2 × 2 grid of round floor holes at x 196/222,
  y 126/160** (owner asked for floor exits, no RJ45, 2026-10-08). That is the space `100W` keeps
  free for `-rj45`'s patch cable, so nothing else moves and the parts mount exactly as in
  `100W`; it is 5 mm from the perfboard's right edge, on the DC side of the mains separation, and
  clear of the far-end LV route (x 234–244, y < 108). The 58 × 75 mm space is too narrow for a
  row of four 20 mm holes, and the 20 mm strip behind the perfboard too shallow for any. Zip-tie
  anchors at the default spot behind each hole. The drill sizes and why the holes are round:
  [../enclosure/wall_openings.md](../enclosure/wall_openings.md).
- **Named by the owner** after the PSU's power; STLs are `<name>-enclosure-base.stl` /
  `-lid.stl` (see [../pipeline/output.md](../pipeline/output.md)).

## Still to check (from datasheets, not measured)

- S-100-5: bottom holes 120 mm apart lengthwise, 80 mm across, nearest 62 mm from the terminal
  end (Mean Well S-100F case 902). Nothing inside should sit within 3 mm of the base plate above
  a bottom hole.
- JST pigtail housings pass the 15.6 × 10.2 mm slot (print `test-prints/jst-sm-3pin-coupon.stl` to check);
  in `-leds-on-floor`, that they pass an 18 mm hole drilled in the board.
- C14 flange overhang (~11 mm) and body depth (assumed 35 of the 60 mm).
- RJ45 outside flange (assumed ≤ the 29 mm nut).

## Gotchas

- Four JST-SM exits carry at most 12 A (3 A per contact) of the PSU's 20 A.
- The lid has 1.2 mm to spare on the A1 bed; any extra length needs a shorter `lid.tab_pull` or a
  bigger printer.
- Feed the JST pigtails out through the slots before screwing the perfboard down (20 mm zone).
- `-leds-on-floor`: drill the mounting board through the floor holes with the box screwed down
  and still empty — a mounted perfboard is 5 mm from the left-hand holes and in the drill's way.

## Related

- [../enclosure/wire_routing.md](../enclosure/wire_routing.md) — the low-voltage route and loops.
- [../enclosure/lid_closure.md](../enclosure/lid_closure.md) — lid and zip-tie lock.
- [../enclosure/psu_mount.md](../enclosure/psu_mount.md) — PSU hole source, bolt depth, `ac_side`.

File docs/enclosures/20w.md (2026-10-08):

# 20W

Path: [docs](../README.md) › [enclosures](README.md) › **20w**
Parent: [README.md](README.md)
**Code:** `enclosures/20W/enclosure.yaml`, `components/psu/s-20-5.yaml`
**Covers:** the S-20-5 enclosure: layout decisions and the measurements still owed.

## What it does

Interior 184 × 118 × 55 mm; base prints at 216.8 × 122.8 × 58, lid at 204.8 × 122.8 × 9.4, and
both together on one A1 plate (`20W-enclosure-plate.stl`, 216.8 × 250.6). On
one line, left to right: the C14 lying down in the left wall (toward the front), the S-20-5 with
its terminals facing the front wall (28 mm of terminal space), and the DIKAVS perfboard turned
90° to run parallel to the PSU, against the back wall. Two round JST-SM holes through the floor
in front of the perfboard.
Slide-lock lid with a zip-tie lock on the right wall; three mounting tabs on the short walls.

## Decisions

- **Layout is the owner's (2026-10-08):** inlet on the left short wall, PSU "wires pointing
  down" (terminals to the front), perfboard beside and parallel to it, LED exits in the floor
  ("on the bottom") next to the perfboard. With the terminals to the front, AC (L, N, ⏚) is on the
  left — toward the inlet — and DC on the right — toward the perfboard, so no wires cross; the
  side rule confirms it. This needed PSUs that face the front/back walls, added to the builder
  for this enclosure ([../enclosure/psu_mount.md](../enclosure/psu_mount.md)).
- **Inlet at u = 36, toward the front**: its rear faces the PSU's left side close to the
  terminals, and its wire zone (x 35–60) leads straight forward into the terminal space. 36 is
  the closest its 69 mm flange gets to the front corner.
- **PSU at x = 60** = inlet body (35) + its wire zone (25). **Perfboard 5 mm right of the PSU**
  and 3 mm from the back wall (like the PSU), leaving 34 mm in front of it for the LED holes.
  **Changed 2026-10-08:** was 20 mm from the front wall; the round 20 mm holes and their anchors
  need 34.
- **Height 55 mm, set by the inlet's flange nuts** (same reason as [100w.md](100w.md)); the
  S-20-5 alone (34 + 3.5 pads) would allow ~45. Upright, the inlet would need ~66.
- **LED exits in the floor strip between the perfboard and the front wall**: round 20 mm holes
  at y = 12 (2 mm off the front wall), x = 140 and 166 as before, so the board is drilled
  straight through them (owner, 2026-10-08; sizes in
  [../enclosure/wall_openings.md](../enclosure/wall_openings.md)). Zip-tie anchors 16 mm behind
  each hole (`anchor_at`), between it and the perfboard, on the pigtails' path; the default spot
  (18 mm) would touch the board. **Changed 2026-10-08:** were 15.6 × 10.2 slots at y = 10,
  anchors 10 mm to their right; the owner could not drill the board through a slot.
  **Changed 2026-10-08:** first built in the front wall — "bottom" had been read as the bottom
  of the top view; the owner meant the floor.
- **Base and lid fit one plate** (owner, 2026-10-08). That took three changes: mounting tabs
  moved to the short walls (the box is short, so long-wall tabs were the only thing making it
  deep), the zip-tie lugs moved to the right short wall (u = 59), and the width went from 122 to
  118 — terminal space 30 → 28 (overriding the library value) and the gap behind the PSU 5 → 3.
  The plate is 250.6 mm deep, 3.4 mm inside the 254 mm usable.
- **Three tabs: left wall at u = 100 (clear of the inlet flange), right wall at u = 20 and 98.**
- **Vents in the back wall behind the PSU's far end** (3 mm air gap), plus lid slots over the PSU. The front
  wall is taken by the terminal wiring.

## Still to check (photo estimates, not measured)

- S-20-5 bottom holes: on the AC-side long edge (owner); ~4.5 mm in from it and ~5.5 mm from
  the terminal end are photo estimates. Centre spacing 67.6 mm assumes "64.6 mm between hole
  edges" meant inner edges of ~3 mm holes. Slots allow ±2 mm along the length.
- S-20-5 height (34 mm assumed from the side photo).
- The label lists 100–120 V / 200–220 V input: if the unit has a voltage selector, it must be on
  the 220 V setting for 230 V mains.

## Gotchas

- **The board under the box must be drilled at the LED holes** (owner mounts it on a wooden
  board and runs the LED wires through it, 2026-10-08): 18 mm, straight through each 20 mm hole,
  with the box screwed down and empty. The BOM also gives the hole centres from the left
  mounting tab.
- Each JST-SM contact is rated 3 A; the PSU's 4 A needs both exits sharing the load.

## Related

- [100w.md](100w.md) — the first enclosure; same inlet, lid, and nut-height reasoning.
- [../enclosure/psu_mount.md](../enclosure/psu_mount.md) — PSU orientations and the local frame.

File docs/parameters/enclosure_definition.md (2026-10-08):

# Enclosure definition

Path: [docs](../README.md) › [parameters](README.md) › **enclosure_definition**
Parent: [README.md](README.md)
**Code:** `enclosures/<name>/enclosure.yaml`, `enclosure_builder/config.py`
**Covers:** the schema an agent writes to create a new enclosure. Example:
`enclosures/100W/enclosure.yaml`.

## What it does

| key | meaning |
|---|---|
| `name` | must equal the directory name |
| `extends` | optional: another enclosure whose YAML is merged underneath this one |
| `box.inner` | `[L, W, H]` interior size |
| `psu` | `part`, `at: [x, y]` (footprint corner with smallest x, y), `terminals: left\|right\|front\|back` (the wall the terminal end faces), optional `lv_route: far_end` (left/right only), `lv_gap` |
| `perfboards[]` | `part`, `at: [x, y]` (board corner with smallest x, y), `rotate: 0\|90`, optional `min_standoff`, `clearance: {left\|right\|front\|back: mm}` |
| `panel_parts[]` | `part`, `wall`, `u`, `z` (cutout centre), `rotate: 0\|90` |
| `wire_holes[]` | `wall`, `u`, `z` and either `d` (round) or `part` (from `components/passthrough/`); `wall: floor` takes `at: [x, y]`, `rotate` (slot direction; for a round hole, only where the default anchor goes), optional `anchor_at: [dx, dy]`; optional `tie_anchor`, `inside_depth` |
| `vents` | `lid_over_psu: bool`, `walls[]`: `{wall, u: [from, to], z: [from, to]}` regions |
| `mounting` | `style: tabs\|floor`, `screw_d`, `head_d`, `tabs[]: {wall, u}` or `floor_holes[]: [x, y]` |
| `lid.tab_u` | where the lid's detent tab sits on the left wall (keep it clear of left-wall parts) |
| `lid.lock_lug` | `{wall: front\|back, u}` adds the zip-tie lock lugs |
| `lid.tongues` | `auto`, a list of u, or `{front: [...], back: [...]}` |
| `printer.bed` | override if this enclosure is printed elsewhere |
| `printer.support_margin` | bed room (mm) outside each wall whose holes need supports |

Any key from `config/defaults.yaml` may also be overridden here.

## Decisions

- **The interior size is stated, not computed from the parts.** Auto-sizing would need an
  auto-layout engine whose choices (where the inlet goes, which side the perfboard sits) are
  exactly the decisions the owner wants to make. Instead the agent places parts explicitly and
  the [validator](../pipeline/validation.md) rejects anything that collides or does not fit.
- **Positions are corners for boxes (`at`) and centres for wall features (`u`, `z`).** A box is
  measured from a wall to its edge; a hole is measured to its centre. Matching how one measures
  avoids off-by-half-width errors.
- **`terminals:` instead of a free rotation for the PSU.** The PSU is only ever laid flat along
  the box length; the only real choice is which end faces the inlet. A free angle would invite
  layouts the validator cannot check with axis-aligned boxes.
- **Round wire holes are inline; connector slots come from the library.** A round hole is just
  a diameter, but a connector slot carries a datasheet-derived size worth citing once.
- **A variant `extends` its base and restates only lists it changes** (lists replace
  wholesale — see [README.md](README.md)).

## Creating a new enclosure

1. Ask the owner which PSU, perfboard(s) and panel parts. For any part without a library file,
   find the manufacturer's drawing first and ask the owner only to verify it or for what is not
   documented (root decision in [../README.md](../README.md)). Every part needs its wiring space
   (`cable`, `terminal_clearance`, `inside_depth`).
2. Copy an existing `enclosure.yaml` into `enclosures/<new-name>/` (or `extends:` it), set
   `name`, place parts. Put the inlet beside the PSU's terminal end and connectors' cable zones
   where their cables can reach the board they serve.
3. `python build.py <new-name>`; fix every ERROR; look at `preview/*.png`.
4. Add the enclosure to [../enclosures/README.md](../enclosures/README.md) with a page recording
   its layout decisions.

## Related

- [component_library.md](component_library.md) — the files `part:` refers to.
- [../pipeline/validation.md](../pipeline/validation.md) — what the build checks about this file.

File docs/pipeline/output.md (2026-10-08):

# Output

Path: [docs](../README.md) › [pipeline](README.md) › **output**
Parent: [README.md](README.md)
**Code:** `enclosure_builder/emit.py`, `enclosure_builder/render.py`, `enclosure_builder/cli.py`, `build.py`
**Covers:** what a build writes and how OpenSCAD is driven.

## What it does

Per enclosure, under `enclosures/<name>/`:

- `build/params.scad` — every scalar and primitive list as SCAD globals.
- `build/{base,lid,assembly,interior}.scad` — wrappers: include the library, include the params,
  call one part module. Open these in the OpenSCAD GUI to inspect.
- `stl/<name>-enclosure-base.stl`, `stl/<name>-enclosure-lid.stl` — already in print
  orientation.
- `stl/<name>-enclosure-plate.stl` — base and lid arranged together, written only when both fit
  on one bed (`validate.plate_layout`: lid behind the base, else beside it, 5 mm apart, within
  `bed - bed_margin`). The owner asked to print an enclosure in one go (2026-10-08); a stale plate
  file is deleted when the parts stop fitting together. The enclosure name is in the file name (owner's convention, 2026-10-08) so a file
  copied into a slicer or another folder still says which enclosure it belongs to.
- `preview/*.png` — closed box from two sides, open box with parts as coloured blocks and wiring
  zones in translucent orange (also from above), the empty base without lid from two sides and straight down, lid
  as printed.
- `BOM.md` — the three key renders at the top (empty base, base with parts, closed — the owner
  wants them visible for every enclosure, 2026-10-08), printed parts with sizes and which
  openings were left without a self-supporting top
  (so the slicer's support settings can be chosen knowingly), how to close/open the lid, hardware totals with what each
  is for, where to drill the mounting surface under floor wire exits (for a round hole: the drill
  to put straight through it, see [../enclosure/wall_openings.md](../enclosure/wall_openings.md)), "Check before printing"
  (datasheet values), warnings.

`build.py --coupon <passthrough part>` writes `test-prints/<part>-coupon.stl`: a wall-thick plate
with one slot cut exactly as in a wall, printed standing up, to test-fit a connector in minutes
before printing a base (added after the 20W's first LED slots were too small, 2026-10-08).

## Decisions

- **Wrappers `include` the library by relative path**, so the repository can move and the
  generated files still open in the GUI.
- **STLs are exported in print orientation** (lid flipped), so they can be dropped onto the
  slicer bed without rotating — the orientation is part of the support-free design.
- **Manifold backend, previews with `--render`.** Manifold renders in seconds where CGAL takes
  minutes on the vent patterns; preview-mode PNGs showed see-through artefacts on differenced
  geometry that looked like real holes.
- **Parts in previews are coloured blocks (`GHOSTS`)**, not models: enough to judge clearances
  and spot a misplaced part, with no CAD files of third-party parts to maintain.
- **OpenSCAD output containing `ERROR` fails the build**; warnings are printed.

## Related

- [validation.md](validation.md) — runs before anything here is written.
- [../enclosure/printability.md](../enclosure/printability.md) — why the orientations are fixed.

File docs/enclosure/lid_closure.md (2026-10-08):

# Lid closure

Path: [docs](../README.md) › [enclosure](README.md) › **lid_closure**
Parent: [README.md](README.md)
**Code:** `scad/enclosure.scad` (`lid`, `lid_plate2d`, `lid_lip`, `lid_tooth`, `lock_cutters`), `enclosure_builder/layout.py` (`place_lid_lock`), `config/defaults.yaml` (`lid:`)
**Covers:** how the lid locates, locks and comes off.

## What it does

Drop-and-slide, no hardware. The lid is lowered onto the box `lid.slide` (10 mm) toward the left
wall from its closed position, then slid right:

- **Tongues** on the lid lip (ends + middle of both long walls) drop through open-top notches in
  the walls, then slide under a 3 mm ledge left above a slot in each wall. They hold the lid down.
- A **flexible tab** cut into the lid plate at the left wall carries a **tooth** underneath. While
  sliding, the tooth rides over the left wall's top on a 45° ramp, then drops inside it; its
  vertical face then stops the lid sliding back. The tab's tip sticks out 4 mm past the wall as a
  finger pull.
- To open: lift the pull with a fingertip (~2.5 mm), slide the lid left, lift it off.

## Decisions

### Drop-and-slide with a detent tab

**Why.** Owner requirement (2026-10-07): the lid must not come undone, must open repeatedly, and
must open without bolts and nuts. The tongues give positive hold against lifting across the whole
length; the only flexing part is the tab, which bends ~1 % (PETG tolerates this indefinitely), and
it only flexes while opening or closing. A 10 mm slide needs no free space around the installed
box, unlike a full-length sliding lid.
**Rejected.** Snap hooks on the lip pressed through wall windows: needs several hooks squeezed at
once, and the hooks' retaining faces would be horizontal overhangs when printed. Full sliding
dovetail lid: needs a lid-length of free space beside the mounted box. Quarter-turn cam latches:
extra printed parts and an M3 axle per latch. Hinge + latch: hinge knuckles add overhangs and
still need a latch.
**Constrains.** The left lip segment stops `slide` short of the left wall, and has a gap under
the tab. Long-wall features must stay clear of the tongue notches/slots (they are wall features,
so the validator enforces it). Nothing may sit on the left wall's outside top where the tooth
travels (`lid lock tab` feature). The C14 flange in 100W is therefore not at the tab.

**Changed 2026-10-07:** previously M3 bolts through the lid into hex nuts side-loaded into bosses
outside the walls, because it was the most secure M3-only closure. Changed because the owner does
not want to undo bolts to reach the electronics; bolts are acceptable for assembly, not for
opening. The bosses are gone, which also shrank the footprint by 15 mm.

### Optional zip-tie lock (`lid.lock_lug`)

**Why.** Owner requirement (2026-10-07): the box will be at a festival (Midburn), and people who
are not thinking clearly must not be able to open the lid and reach 230 V. A lug on the lid plate
sits 0.4 mm above a lug on a long wall; their 5 mm holes line up only when the lid is closed. A
zip tie through both stops the lid sliding (so the tooth cannot be bypassed) and lifting. It
needs cutters to open, which is the point.
**Rejected.** A tie through the detent tab's finger pull: the pull would have to grow ~8 mm to
take a hole, and the lid is already within 1.2 mm of the A1 bed in length. A hole through wall
and lid lip: the tie could not be closed inside the box.
**Constrains.** The lugs may go on any wall: on a long wall they shear apart when the lid
slides, on a short wall they pull apart — the tie stops both. A short wall keeps the lid narrow
(used by 20W so base and lid share one plate). The wall lug's underside is 45° so it prints
without support; the lugs add `lug_reach` (12 mm) to base and lid, which the bed check includes.
**Changed 2026-10-08:** lugs were limited to the long walls; that was an unnecessary restriction.

### Tongue and ledge faces are parallel 45° slopes

**Why.** A flat ledge underside would be a horizontal overhang in the base, and a flat tongue top
would be one in the flipped lid. 45° faces print on both parts without supports. The hold is
still positive: to release by lifting, the lid's lip would have to bend inward 2 mm along its
length, which the lip corners and the closed lip ring prevent.
**Constrains.** `lid.lip_h` must leave the tongue tip ≥ 1 mm thick and the slot open at the
wall's outer face; `place_lid_lock` errors otherwise.

- **Tongues on the long walls only, at both ends and the middle (if > 150 mm).** The slide runs
  along the length, so only long walls can take slots; the middle tongue stops a 240 mm lid from
  bowing up between the ends.
- **In `auto` mode each tongue slides toward the middle until it clears that wall's other
  features**, and the build lists the move under "Check before printing". A flange reaching up
  into the lock zone (the rotated C14 in 100W moves the back-left tongue from 22 to
  88 mm) should not force the box taller. `lid.tongues` may also be a list, or a `{front, back}`
  map of lists, to place them by hand.
- **`slide` > tongue width + clearance** so the locked tongue is fully under the ledge, not half
  over the notch.
- **Tooth 2 mm tall, vertical face 0.4 mm from the wall's inner face.** 2 mm is enough that a knock
  cannot ride the lid back over it; lifting the tab 2.5 mm clears it.
- **Tab 30 mm long, 14 wide, slits end in round reliefs.** Length sets the bending strain (~1 %
  at 2.5 mm lift); the round ends stop cracks starting at the slit tips.
- **Lip 7 mm tall, 1.6 mm thick, 0.3 mm clearance.** Tall enough to carry the tongues; 0.3 mm
  covers PETG's error on a 240 mm part without visible play.

## Gotchas

- `lid.tab_u` must keep the tab clear of whatever is on the left wall; the validator reports a
  collision with `lid lock tab`.
- The lip zone (top `lip_h` of the interior) is reserved: through-cuts stay below
  `H − lip_h − margin`, keep-outs below `H − lip_h`.

## Related

- [printability.md](printability.md) — why every lock face is 45° or vertical.
- [ventilation.md](ventilation.md) — lid slots avoid the tab and the slide strip.
- [shell.md](shell.md) — the shared outline the lid plate is cut from.

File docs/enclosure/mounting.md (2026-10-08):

# Mounting

Path: [docs](../README.md) › [enclosure](README.md) › **mounting**
Parent: [README.md](README.md)
**Code:** `enclosure_builder/layout.py` (`place_mounting`), `scad/enclosure.scad` (`tab`, `FLOOR_MOUNTS` in `floor_cutters`), `config/defaults.yaml` (`mounting:`)
**Covers:** how the enclosure is fixed to whatever it is mounted on.

## What it does

`style: tabs` (default) adds flat ears flush with the floor's underside on any wall at any `u`,
each with one countersunk hole and two triangular side ribs. `style: floor` instead puts
countersunk holes through the floor at given interior `[x, y]`.

## Decisions

- **Tabs by default.** Screws are driven from above with the lid on and the parts installed,
  and nothing inside has to avoid them. Floor holes are the fallback when tabs would push the
  base past the bed; the validator rejects floor holes under any solid
  keep-out, so they always land in reachable free floor.
- **Screw size is a parameter (`screw_d`, `head_d`) and is not M3.** The owner asked for these
  holes to be parameters; they take whatever suits the surface (wood screws, M4). Default 4.5 mm
  through / 9 mm countersink fits #8 and M4 screws.
- **Ribs on the tab's side edges, not across its middle**, so a screwdriver and screw head reach
  the hole straight down. The rib slope is 45°, so it prints without supports.
- **Hole centre at 55 % of the tab length from the wall** — clear of the wall for the screw head,
  but not so far out that the tab levers off.

## Related

- [shell.md](shell.md) — tabs extend the base's footprint, which the bed check includes.
- [../pipeline/validation.md](../pipeline/validation.md) — floor-hole and bed-fit checks.

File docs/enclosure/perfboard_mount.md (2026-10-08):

# Perfboard mount

Path: [docs](../README.md) › [enclosure](README.md) › **perfboard_mount**
Parent: [README.md](README.md)
**Code:** `components/perfboard/`, `enclosure_builder/layout.py` (`place_perfboards`), `scad/enclosure.scad` (`floor_additions` standoffs, `floor_cutters` nut pockets)
**Covers:** the perfboard component schema and how boards are held.

## What it does

Each board hole gets a printed standoff on the floor. An M3 bolt goes down through the board and
the standoff into a hex nut sitting in a pocket opened from the floor's underside.

Perfboard fields: `size` (outline), `thickness`, `hole_d`, `holes` (any number — 2 for the
DIKAVS board, 4 for most), `component_h` (keep-out above the board).

The DIKAVS board was measured by the owner: 81 × 55, 3.1 mm holes whose edges are 9.6 mm from
the short sides; the holes are assumed centred across the width (they sit on the centre channel
in the photo). An M3 bolt passes a 3.1 mm hole.

## Decisions

### Bolt from the top into a nut under the floor

**Why.** The board can be removed with the lid off while the enclosure stays fixed in place (the
nut cannot fall out: the mounting surface closes the pocket). No inserts (owner).
**Rejected.** Bolt from below with the nut on top of the board: the bolt spins when undoing the
nut once the box is mounted. Nut trapped inside the standoff via a side slot: weakens a 7 mm
standoff.
**Constrains.** Nuts go in before the enclosure is fixed down.

- **Standoff height is derived from the shortest standard bolt that gives at least
  `min_standoff`**, positioned so the bolt tip ends 0.5 mm inside the floor's underside — fully
  through the nut, never proud of the surface the box sits on.
- **Any number of holes.** The owner's first board is held by 2; most boards have 4. The schema
  is a list so neither is special.
- **Standoff OD 7 mm with a 45° foot 3 mm wide.** The nut pocket takes 2.9 of the 3 mm floor
  under each standoff, so without the foot the standoff would hang on a 0.1 mm skin. The foot
  carries the load into the surrounding full-thickness floor and prints without supports.
- **Optional side clearance per board** (`clearance: {left|right|front|back: mm}`, interior
  directions after rotation): free room beside the board's edges for its side connectors and
  their cables. It is a `clearance` keep-out: other wiring may share it, and so may a low-voltage
  wall connector body (an RJ45 coupler at the wall end of the strip — that is the kind of thing
  the room is for); the PSU, other boards and mains parts may not. Added for the 100W-masterbox:
  3 cm on both long sides of the MAX485 board (modules overhang) and 3 cm on one long side of the
  ESP32 board (USB-C cable), owner 2026-10-08. Shown light blue in previews.
- **`rotate: 0 | 90` only.** Boards are laid parallel to the walls; arbitrary angles would break
  the axis-aligned keep-out check.

## Related

- [printability.md](printability.md) — bridged nut pocket.
- [psu_mount.md](psu_mount.md) — the other floor-bolted part; same bolt-length-first approach.

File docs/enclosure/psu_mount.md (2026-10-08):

# PSU mount

Path: [docs](../README.md) › [enclosure](README.md) › **psu_mount**
Parent: [README.md](README.md)
**Code:** `components/psu/s-100-5.yaml`, `enclosure_builder/layout.py` (`place_psu`), `scad/enclosure.scad` (`floor_additions` pads, `floor_cutters` floor bolts)
**Covers:** the PSU component schema and how a PSU is fastened to the floor.

## What it does

The PSU lies flat on four printed pads. M3 bolts come up from under the floor, through short
slots in floor and pads, into the PSU's own threaded bottom holes. Heads sit in counterbores in
the floor's underside. The terminal end gets a wiring zone (`terminal_clearance`).

PSU fields: `size` (local frame: x from the terminal end), `holes`, `hole_slack` (± slot along x),
`max_penetration`, `bolt_len`, `terminal_clearance`, `ac_side`, `terminal_block` (preview only), plus the
instance's `lv_route` (see [wire_routing.md](wire_routing.md)) and the
library `source` / `verified` / `check` fields.

## Decisions

### Local frame, four orientations, all rotations

Component holes are given in the PSU's own frame: x from the terminal end, y across, growing
toward the left of someone facing the terminal block — the AC side when `ac_side: left`.
`terminals: left | right | front | back` places that frame by rotation only (`psu_frame`), never
by mirroring, so a PSU whose holes are all on one edge (the S-20-5's are on the AC edge) lands
the way it physically sits. Bolt slots run along the PSU's length whichever way it faces.
**Why.** The 20W enclosure needed the PSU facing the front wall; before that only left/right
existed, and "right" mirrored the PSU, which was harmless only because the S-100-5's holes are
symmetric. `holes_alt` exists for a PSU whose holes are known up to a mirror image: those
positions are cut and padded but not bolted.

### Through the floor into the PSU's own threads

**Why.** No nuts, no inserts, and the PSU's threads are metal (owner: minimal non-printed parts).
Bolting from below leaves the top of the PSU free for airflow and terminal access.
**Rejected.** The three M3 holes on the PSU's long side: the PSU would have to touch that wall,
blocking its side vents. Printed clamps: more plastic under heat and creep load.
**Constrains.** The PSU is fitted before the enclosure is fixed to its surface.

### Bolt depth fixed at 3 mm by the pad height

`pad_h = (head_h + head_recess + layer_h) + (bolt_len − max_penetration) − floor`.
**Why.** The owner flagged that these PSUs have shallow mounting holes and that a deep screw can
short the PCB. The S-100F datasheet (the original this clone copies) gives no limit. Mean Well's
installation manual says screws must keep insulation distance from internal parts and to read
the limit from each case drawing; on the newer drawings that state one, the smallest is 3 mm
(LRS-350 bottom holes, "L=3mm"). So `max_penetration: 3`, and the geometry, not the user, enforces
it: with M3 × 6 the pads are 3.5 mm tall and the tip enters exactly 3 mm. The BOM says not to
substitute a longer bolt.
**Constrains.** Changing `bolt_len` or the floor moves the PSU up or down; keep-outs follow.

- **Hole positions from the Mean Well S-100F drawing (case 902):** 62 and 182 mm from the
  terminal end, rows 9 mm from each long edge (120 × 80 pitch). The clone maker's own drawing
  (Finglai S-100) is identical, and its side-face holes match the owner's unit. An earlier photo
  suggested different positions; that was perspective.
- **`hole_slack: 1.5`** — slots only absorb print and sheet-metal tolerance now that the
  positions come from the manufacturer. (Was ±8 mm while unverified.)
- **`terminal_clearance: 40`.** The 7 terminals (1 L, 2 N, 3 FG, 4–5 −V, 6–7 +V) face up at
  the end, wires leave toward the end wall. 40 mm fits ferrules, the bend of 14 AWG output wire,
  and the inlet's wires arriving from the side. It is a `wiring` zone, so the inlet's cable zone
  may meet it but nothing solid may enter it. (Was 25 mm; the owner pointed out wires need room.)
- **`ac_side: left` for the S-100-5**: facing the block, L, N, FG are on the left, −V/+V on the
  right (owner's photo, matching the S-100F pin numbering). It drives the mains/low-voltage side
  rule in [README.md](README.md).
- **Lid vents skip the terminal end** — see [ventilation.md](ventilation.md).

## Related

- [README.md](README.md) — wiring zones, the rule that gives the terminals their space.
- [printability.md](printability.md) — the bridged counterbore under each bolt.
- [../enclosures/100w.md](../enclosures/100w.md) — what the owner should check on the unit.

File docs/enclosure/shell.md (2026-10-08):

# Shell

Path: [docs](../README.md) › [enclosure](README.md) › **shell**
Parent: [README.md](README.md)
**Code:** `scad/enclosure.scad` (`outline2d`, `base`, `wall_frame`, `wall_prism`), `enclosure_builder/layout.py` (`place_box`)
**Covers:** the box itself — floor, walls, the outline shared with the lid — and the wall frame
every wall feature is placed in.

## What it does

`outline2d()` is the outer footprint: the wall rectangle with rounded vertical edges. The base
extrudes it from the floor's underside to the wall top and subtracts the interior box; the lid
plate is the same outline plus its finger pull.

`wall_frame(wall, u, z)` maps a local frame (x along the wall, y outward through it, z up, origin
on the interior face) onto any wall, so every wall cutter is written once.

## Decisions

- **Base and lid share one outline.** The lid's edge lines up with the walls exactly,
  with no separate dimension to keep in sync.
- **`wall_frame` uses a mirroring matrix for the front and right walls** so that local x always
  runs in the global +x/+y direction (the `u` convention in
  [../parameters/README.md](../parameters/README.md)). All cutters are symmetric or built from
  explicit `u` offsets, so the mirror has no visible effect.

## Gotchas

- Wall cutters extend 1 mm beyond both faces (`wall_prism(-1, WALL + 1)`) to avoid coplanar
  faces; anything that must stop inside the wall (pockets) passes its own depth.

## Related

- [lid_closure.md](lid_closure.md) — the lid plate cut from the same outline.
- [wall_openings.md](wall_openings.md) — the main user of `wall_frame`.

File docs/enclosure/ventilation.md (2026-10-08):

# Ventilation

Path: [docs](../README.md) › [enclosure](README.md) › **ventilation**
Parent: [README.md](README.md)
**Code:** `enclosure_builder/layout.py` (`place_vents`), `scad/enclosure.scad` (`WALL_SLOTS` in `wall_cutters`, `LID_SLOTS` in `lid`), `config/defaults.yaml` (`vents:`)
**Covers:** passive cooling for the PSU.

## What it does

Each `vents.walls[]` region (`wall`, `u` range, `z` range) is filled with vertical slots at
`pitch`, skipping any slot that would come within `feature_margin` of another wall feature. With
`lid_over_psu`, the lid gets slots across the PSU's width over its body, but not over its
terminal end.

## Decisions

### Passive convection: low wall intake, lid exhaust

**Why.** The owner requires the PSU to be well ventilated. A 100 W supply at ~85 % efficiency
dissipates ~15 W; the S-series case is itself perforated and designed for free air. Cool air
enters through low slots in the walls beside the PSU, the PSU's pads leave a gap under it, and
warm air leaves through the lid above it.
**Rejected.** A fan: an extra part, noise, and a failure point; not needed at this dissipation if
the slots are kept clear. Revisit if the PSU runs near 20 A continuously in a warm place.
Floor vents: blocked whenever the enclosure is fixed flat to a surface.
**Constrains.** Do not place parts that block the wall regions beside the PSU, and do not mount
the enclosure lid-down.

- **Vents are placed last and skip conflicts instead of erroring.** A vent region is "as many
  slots as fit here", so a new wire hole should not force the agent to re-plan the vents.
- **Slots are almond-topped**: the 45° point ends at the region's top `z`, so the slats print with
  no bridge (see [printability.md](printability.md)).
- **Slot width 2.5 mm.** Well under the 12.5 mm finger probe (mains is inside), and small enough
  to keep out most debris; 2.5 also bridges cleanly at the slot tops.
- **No lid slots over the PSU terminals** (`terminal_block.len + 10` mm skipped): anything
  dropped through the lid must not land on mains screw terminals.
- **No lid slots within `tab_len + 4` of the left edge or over the slide strip**, so the detent
  tab and its slits stay solid plate.
- **Slot pitch 6 mm** leaves 3.5 mm pillars — stiff enough that a 2.4 mm wall with 30 slots does
  not become floppy.

## Related

- [psu_mount.md](psu_mount.md) — pads that create the under-PSU air gap.
- [lid_closure.md](lid_closure.md) — lid slots stay inside the lip.
- [wall_openings.md](wall_openings.md) — features vents avoid.

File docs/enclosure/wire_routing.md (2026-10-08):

# Wire routing

Path: [docs](../README.md) › [enclosure](README.md) › **wire_routing**
Parent: [README.md](README.md)
**Code:** `enclosure_builder/layout.py` (`place_lv_route`), `enclosure_builder/validate.py` (side rule), `scad/enclosure.scad` (`wire_guide`), `config/defaults.yaml` (`wire_guides:`)
**Covers:** how low-voltage wires get from the PSU's DC terminals to the electronics without
meeting mains wiring, and the printed loops that hold them.

## What it does

With `psu.lv_route: far_end`, the build reserves a wiring channel along the PSU's DC-side long
face (between the PSU and that wall) and another between the PSU's far end and the end wall,
and puts printed wire loops on the walls of both: every `spacing` mm along the side channel's
wall and two on the far-end wall. Low-voltage wires leave the DC terminals,
thread through the loops along the PSU, and come round its far end to the AC side.

## Decisions

### Low voltage may sit on the AC side if its wires go round the far end

**Why.** Owner design (2026-10-07). Putting the inlet and the perfboard in the same band (the
AC side) avoids a wasted band on each side of the PSU; routing the DC wires the long way round
the PSU means they never pass the terminal end on the AC side, where the mains wires are.
**Rule (validator).** A low-voltage part on the AC side is allowed only with `lv_route` set, and
only if it is at least `psu.lv_gap` (20 mm) from the mains region: the bounding box of every
mains body, mains cable zone and the PSU's terminal space (the inlet's wires run somewhere
inside that hull). Without `lv_route`, low-voltage parts must be on the DC side.
**Changed 2026-10-08:** the distance used to be measured only along the PSU's length, which
banned low voltage from the whole width of the box near the mains end — e.g. behind an inlet
mounted next to the terminals, where no mains wire goes (owner pointed out the wasted space).
**Rejected.** PSU centred with mains on one side and electronics on the other (the previous
layout): a 60 mm mains band with one inlet in it and empty floor beside, which made the box
239 mm wide and too wide for mounting tabs.

### Loops lean on the wall, sized for loose wires

**Why.** Owner (2026-10-08): with the wall as one side the loop is stronger — it is anchored
along its whole height, not only by two thin feet — and it uses less plastic. Each loop is a leg
standing on the floor `w` out from the wall plus a 45° roof rising from the leg's top back into
the wall, so it prints in place without support; the roof is kept `t` thick square to its face.
The tunnel is 7 mm out from the wall and 8 mm tall before the roof — two 14 AWG power leads plus
several signal wires, threaded through without connectors.
**Rejected.** Free-standing arches: weaker, and two walls instead of one. Tunnels big enough for
an XT60 (9 × 17 mm): asked for, then dropped by the owner (2026-10-08) — wires only. The optional
`wire_guides.fits: [a, b]` check remains for an enclosure that does need a connector to pass.
**Constrains.** Loops are wall features: vents skip them, and through-cuts keep
`feature_margin` from them. The roof's top (~17 mm) must stay below the lid lip; the build checks.
**Changed 2026-10-08:** previously free-standing pointed arches centred in the channel.

- **Channel width is checked against the loop's reach from the wall** (w + t + 1 mm), so a layout cannot squeeze
  the route shut. The channels are `wiring` keep-outs and loops are `anchor`s, so nothing solid
  may be put in the route.
- **Loops every 45 mm** keep a bundle from sagging into the PSU's side; two in the far-end
  channel hold the turn.

## Related

- [README.md](README.md) — the mains/low-voltage side rule this extends.
- [psu_mount.md](psu_mount.md) — `ac_side` and the terminal zone the route starts from.
- [printability.md](printability.md) — why every overhang here is 45°.

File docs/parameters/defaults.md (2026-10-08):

# Defaults

Path: [docs](../README.md) › [parameters](README.md) › **defaults**
Parent: [README.md](README.md)
**Code:** `config/defaults.yaml`
**Covers:** the house-style values every enclosure inherits. Values whose reason is a feature's
design are explained on that feature's page; this page covers the global ones.

## What it does

Supplies every key an enclosure may omit. Anything here can be overridden in an `enclosure.yaml`.

## Decisions

- **`printer.bed: [256, 256]`** — the Bambu Lab A1, the owner's main printer (confirmed
  2026-10-07; a Voron Trident may come later and is larger, so A1 stays the limit).
- **`printer.bed_margin: 2`** — total mm per axis kept free so a part is never exactly the bed's
  size (slicers and bed clips need a little room).
- **`printer.support_margin: 0`** — bed room outside walls whose holes need supports; off by
  default because the earlier enclosures were sized before it existed and print with bridges.
- **`printer.layer_h: 0.2`** is the sacrificial bridge-layer height, matching the common 0.2 mm
  profile. It must equal the slicer's layer height for the bridge trick to land on a layer
  boundary (see [../enclosure/printability.md](../enclosure/printability.md)).
- **`box.wall: 2.4`** = six 0.4 mm perimeters: solid walls with no infill pattern, stiff enough
  for a 230 mm span, thin enough that panel parts' screws reach through.
- **`box.floor: 3.0`.** Must hold M3 nut pockets (2.7 deep) and carry the PSU; thinner floors
  leave the nut pockets breaking through.
- **`box.feature_margin: 2.0`** — minimum solid material between two wall features, roughly the
  minimum that prints as a reliable bridge/pillar at 0.4 mm nozzle.
- **M3 numbers** (`hardware.m3`): 3.4 clearance (3.2 binds on printed holes, which print
  undersize); 6.4 counterbore for a 5.5 head; 0.3 recess so heads never stand proud of the floor's
  underside (the enclosure must sit flat on its mounting surface). Nut pocket clearance 0.3
  (dropped in from below, must slide in freely).
- **`hardware.m3.lengths`** is the list of lengths actually sold in common M3 assortments;
  [length picking](../pipeline/layout_model.md) only chooses from it.
- **`perfboard.min_standoff: 6`** — room under a perfboard for solder joints, clipped leads and a
  wire or two; 3 mm is the bare minimum, 6 avoids shorts against the nut pocket bridges.

## Related

- [component_library.md](component_library.md) — per-part values live there, not here.
- [../enclosure/lid_closure.md](../enclosure/lid_closure.md) — reasons for the `lid:` values (slide-lock geometry).
- [../enclosure/ventilation.md](../enclosure/ventilation.md) — reasons for the `vents:` values.
- [../enclosure/mounting.md](../enclosure/mounting.md) — reasons for the `mounting:` values.

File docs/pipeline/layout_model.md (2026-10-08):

# Layout model

Path: [docs](../README.md) › [pipeline](README.md) › **layout_model**
Parent: [README.md](README.md)
**Code:** `enclosure_builder/layout.py`
**Covers:** the data structure the placement functions fill in, and the rules shared by all of
them. The individual `place_*` functions are documented on their feature pages under
[../enclosure/](../enclosure/README.md).

## What it does

`build_model` creates a `Model` and calls the placement functions in a fixed order: box scalars,
lid lock, PSU, perfboards, panel parts, wire exits, mounting, vents. Each appends to:

- `prims` — named lists that become SCAD globals (`PADS`, `WALL_RECTS`, `LID_TONGUES`, …);
- `keepouts` — `Box3` volumes in interior coordinates, kind `solid`, `wiring` or `anchor`;
- `wall_feats` — `WallFeat` rectangles in a wall's (u, z) plane, `through` or outside-only,
  with a `group` so a part's own features are not checked against each other;
- `bom`, `checks` (datasheet values to confirm), `warnings`, `errors`.

`Model.wiring()` adds a wiring keep-out and its orange preview ghost in one call, so no part can
reserve wire space without it being visible. `Model.note_verification()` reports each library
part once however many times it is placed.

## Decisions

- **Primitives are flat lists of numbers and strings**, not SCAD objects. OpenSCAD has no
  dictionaries in stable releases; positional lists are what its `for` loops consume. The list
  layouts are documented by comments at each use in `scad/enclosure.scad`.
- **A part's own body and cable zone do not overlap**: the cable zone starts where the body
  ends (`wall_box(start=...)`), so the generic overlap check needs no same-part exception.
- **Vents are placed last** because they fill whatever wall area is left (see
  [../enclosure/ventilation.md](../enclosure/ventilation.md)).
- **`clearance` keep-outs** (perfboard side room) may overlap wiring, anchors and other
  clearance, plus solids flagged `connector` (non-mains wall connector bodies); see
  [../enclosure/perfboard_mount.md](../enclosure/perfboard_mount.md).
- **Three keep-out kinds.** `solid` (PSU body, perfboard + parts, panel bodies) may not overlap
  anything; `wiring` (PSU terminals, panel cables, wire exits) may overlap other wiring; `anchor` (zip-tie anchors) may
  sit in wiring space because that is where wires are. Without the distinction a tie anchor next
  to the PSU terminals would be a false collision.
- **`pick_length` chooses the shortest standard M3 length meeting a minimum** from
  `hardware.m3.lengths`; geometry is then derived from it (root decision in
  [../README.md](../README.md)).
- **Placement functions append errors instead of raising**, so one build reports every problem
  in the file at once.

## Gotchas

- Keep-outs are axis-aligned boxes; that is why PSUs and boards only rotate in 90° steps.

## Related

- [validation.md](validation.md) — consumes `keepouts` and `wall_feats`.
- [output.md](output.md) — consumes `prims`, `scalars`, `bom`.

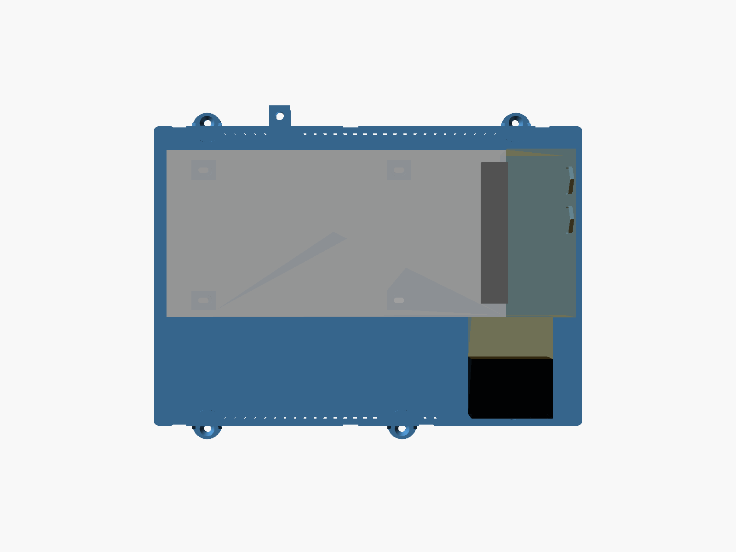
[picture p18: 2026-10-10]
enclosures/100W-power-only/preview/interior_top.png

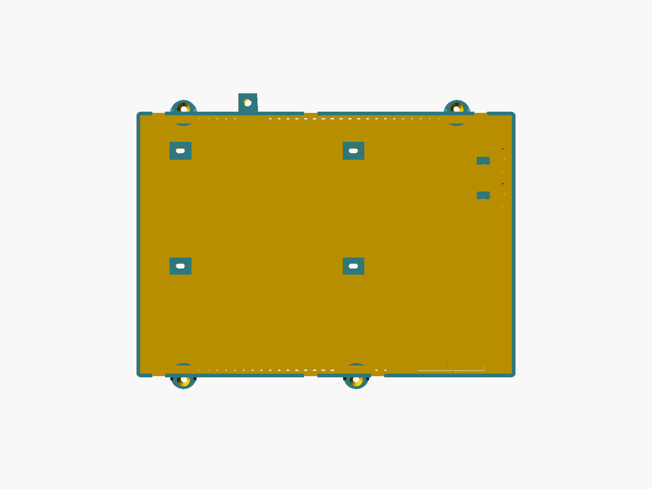
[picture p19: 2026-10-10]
enclosures/100W-power-only/preview/base_top.png

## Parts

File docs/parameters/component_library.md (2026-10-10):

# Component library

Path: [docs](../README.md) › [parameters](README.md) › **component_library**
Parent: [README.md](README.md)
**Code:** `components/psu/`, `components/perfboard/`, `components/panel/`, `enclosure_builder/config.py`
**Covers:** how reusable part descriptions are stored and loaded. What each kind's fields mean is
on the feature page that consumes it.

## What it does

`components/<kind>/<part>.yaml` describes one physical part in its own local frame. An enclosure
names it with `part: <part>`; `config.load_component` loads it, checks `kind:` matches the
directory, and merges the instance's `override:` mapping over it.

Kinds and their consumers:

| kind | consumer page |
|---|---|
| `psu` | [../enclosure/psu_mount.md](../enclosure/psu_mount.md) |
| `perfboard` | [../enclosure/perfboard_mount.md](../enclosure/perfboard_mount.md) |
| `panel` (C14 inlet, RJ45, anything clamped in a wall cutout) | [../enclosure/wall_openings.md](../enclosure/wall_openings.md) |
| `passthrough` (connector-sized wall slots and floor holes with their drill size, e.g. JST SM, XT60 pigtails) | [../enclosure/wall_openings.md](../enclosure/wall_openings.md) |

## Decisions

- **Parts are described in their own frame (e.g. PSU holes measured from its terminal end),
  never in enclosure coordinates.** That is how a datasheet or a caliper reports them, and it
  lets the same file be placed, mirrored or rotated in any enclosure.
- **`kind:` is checked against the directory.** A PSU file accidentally put in `panel/` would
  otherwise be read with the wrong schema and produce plausible but wrong geometry.
- **`verified: true | datasheet | false` on every component.** `true`: measured on the real part
  (record date and what was measured in comments). `datasheet`: from the manufacturer's
  documentation for this exact part; `check:` names the one measurement that confirms it, and it
  is listed once per part under "Check before printing" in the BOM. `false`: guessed (photo,
  similar part); a build warning. See the root decision in [../README.md](../README.md).
- **`source:` records where unmeasured numbers came from**, so a later agent can tell a
  datasheet value from a guess.
- **Panel parts are one generic kind (cutout + optional M3 bolts + flange + inside keep-out)**
  rather than a kind per connector. C14 modules, RJ45 couplers, switches, DC jacks and glands all
  reduce to that shape, so new connectors need a YAML file, not code.

## Gotchas

- `override:` replaces lists wholesale: overriding one PSU hole means restating all four.

## Related

- [enclosure_definition.md](enclosure_definition.md) — how enclosures reference parts.
- [../enclosures/100w.md](../enclosures/100w.md) — which library parts are still unmeasured.

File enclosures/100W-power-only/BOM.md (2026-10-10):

# 100W-power-only — build sheet

GENERATED by `build.py` from `enclosure.yaml`. Do not edit; rebuild instead.

| Base, no lid | Base with parts, no lid | Closed |
|---|---|---|
| base | parts | closed |

Parts are drawn as blocks: grey PSU, green perfboards, black connector bodies; light blue is board clearance, orange is wiring space.

## Printed parts

| File | Print orientation | Size (x × y × z mm) | Supports |
|---|---|---|---|
| `stl/100W-power-only-enclosure-base.stl` | floor on the bed | 246.8 × 200.8 × 58.0 | c14-fuse-switch cutout: flat 47.5 mm top (bridge, or support if your slicer wants it) |
| `stl/100W-power-only-enclosure-lid.stl` | top face on the bed, lip up | 250.8 × 184.8 × 9.4 | none |

Bed: base leaves 7.2 mm spare on its tightest axis; lid leaves 3.2 mm spare on its tightest axis (256 x 256 bed, 2 mm margin kept).

Base and lid do not fit on one plate together; print them separately.

The lid needs no hardware: drop it in shifted toward the left wall, slide it right until the tab clicks. To open, lift the tab at the left edge and slide the lid left.

Print in PETG or ASA, not PLA: the PSU case runs warm at full load and PLA creeps under the bolted PSU pads.

## Hardware

| Qty | Item | Used for |
|---|---|---|
| 2 | M3 hex nut | 2 panel[0] c14-fuse-switch flange, inside |
| 2 | M3 x 10 socket head | 2 panel[0] c14-fuse-switch flange, head outside |
| 4 | M3 x 6 socket head | 4 psu s-100-5, from under the floor into the PSU (enters 3 mm — do not substitute a longer bolt) |
| 4 | screw, shank <= 4.2 mm, head <= 9 mm | 4 fixing the enclosure (user's choice of screw) |

## Interior

242 × 168 × 55 mm (L × W × H), wall 2.4 mm, floor 3.0 mm.

## Check before printing

Taken from datasheets, not measured on your parts:

- psu s-100-5: from Mean Well S-100F datasheet, case No. 902 (https://www.meanwell.com/Upload/PDF/S-100F/S-100F-SPEC.PDF) — bottom M3 holes 120 mm apart along the length and 80 mm across; nearest hole 62 mm from the terminal end
- xt60-f: from Amass XT60-F datasheet V1.2, customer drawing (https://datasheet.lcsc.com/szlcsc/Changzhou-Amass-Elec-XT60Female_C98734.pdf) — the XT60 on your pigtail (and its heat-shrink or XT60H sheath) passes the 16.5 x 9.1 mm slot
- lid: front-wall tongue moved from u=232 to u=165 to clear other features

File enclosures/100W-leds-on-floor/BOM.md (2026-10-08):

# 100W-leds-on-floor — build sheet

GENERATED by `build.py` from `enclosure.yaml`. Do not edit; rebuild instead.

| Base, no lid | Base with parts, no lid | Closed |
|---|---|---|
| base | parts | closed |

Parts are drawn as blocks: grey PSU, green perfboards, black connector bodies; light blue is board clearance, orange is wiring space.

## Printed parts

| File | Print orientation | Size (x × y × z mm) | Supports |
|---|---|---|---|
| `stl/100W-leds-on-floor-enclosure-base.stl` | floor on the bed | 248.8 × 218.8 × 58.0 | c14-fuse-switch cutout: flat 47.5 mm top (bridge, or support if your slicer wants it) |
| `stl/100W-leds-on-floor-enclosure-lid.stl` | top face on the bed, lip up | 252.8 × 202.8 × 9.4 | none |

Bed: base leaves 5.2 mm spare on its tightest axis; lid leaves 1.2 mm spare on its tightest axis (256 x 256 bed, 2 mm margin kept).

Base and lid do not fit on one plate together; print them separately.

The lid needs no hardware: drop it in shifted toward the left wall, slide it right until the tab clicks. To open, lift the tab at the left edge and slide the lid left.

Print in PETG or ASA, not PLA: the PSU case runs warm at full load and PLA creeps under the bolted PSU pads.

## Hardware

| Qty | Item | Used for |
|---|---|---|
| 4 | M3 hex nut | 2 perfboard[0] dikavs-half, in pockets under the floor; 2 panel[0] c14-fuse-switch flange, inside |
| 2 | M3 x 10 socket head | 2 panel[0] c14-fuse-switch flange, head outside |
| 2 | M3 x 12 socket head | 2 perfboard[0] dikavs-half, from the top |
| 4 | M3 x 6 socket head | 4 psu s-100-5, from under the floor into the PSU (enters 3 mm — do not substitute a longer bolt) |
| 4 | screw, shank <= 4.2 mm, head <= 9 mm | 4 fixing the enclosure (user's choice of screw) |

## Interior

244 × 186 × 55 mm (L × W × H), wall 2.4 mm, floor 3.0 mm.

## Drilling the mounting surface

Floor wire exits pass through the board below. Hole centres, measured from the front-wall mounting tab hole (x to the right, y toward the back, looking down on the enclosure):

- x +156.0 mm, y +136.1 mm: drill 18 mm straight through the 20 mm hole, with the enclosure screwed down and empty (the bit clears the plastic by 1 mm all round)
- x +182.0 mm, y +136.1 mm: drill 18 mm straight through the 20 mm hole, with the enclosure screwed down and empty (the bit clears the plastic by 1 mm all round)
- x +156.0 mm, y +170.1 mm: drill 18 mm straight through the 20 mm hole, with the enclosure screwed down and empty (the bit clears the plastic by 1 mm all round)
- x +182.0 mm, y +170.1 mm: drill 18 mm straight through the 20 mm hole, with the enclosure screwed down and empty (the bit clears the plastic by 1 mm all round)

## Check before printing

Taken from datasheets, not measured on your parts:

- psu s-100-5: from Mean Well S-100F datasheet, case No. 902 (https://www.meanwell.com/Upload/PDF/S-100F/S-100F-SPEC.PDF) — bottom M3 holes 120 mm apart along the length and 80 mm across; nearest hole 62 mm from the terminal end
- jst-sm-3pin: from JST SM connector datasheet, housing drawings p.3 (https://www.jst-mfg.com/product/pdf/eng/eSM.pdf) — both housings pass the 15.6 x 10.2 mm slot (wall exits) and an 18 mm drilled hole (floor exits) without squeezing the latch flaps
- lid: back-wall tongue moved from u=22 to u=88 to clear other features

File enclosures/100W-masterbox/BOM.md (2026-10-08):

# 100W-masterbox — build sheet

GENERATED by `build.py` from `enclosure.yaml`. Do not edit; rebuild instead.

| Base, no lid | Base with parts, no lid | Closed |
|---|---|---|
| base | parts | closed |

Parts are drawn as blocks: grey PSU, green perfboards, black connector bodies; light blue is board clearance, orange is wiring space.

## Printed parts

| File | Print orientation | Size (x × y × z mm) | Supports |
|---|---|---|---|
| `stl/100W-masterbox-enclosure-base.stl` | floor on the bed | 248.8 × 248.8 × 58.0 | c14-fuse-switch cutout: flat 47.5 mm top (bridge, or support if your slicer wants it); rj45-bulkhead hole: round 24 mm top (overhang; may want support); rj45-bulkhead hole: round 24 mm top (overhang; may want support); rj45-bulkhead hole: round 24 mm top (overhang; may want support) |
| `stl/100W-masterbox-enclosure-lid.stl` | top face on the bed, lip up | 252.8 × 248.8 × 9.4 | none |

Bed: base leaves 0.2 mm spare on its tightest axis; lid leaves 1.2 mm spare on its tightest axis (256 x 256 bed, 2 mm margin kept).

Base and lid do not fit on one plate together; print them separately.

The lid needs no hardware: drop it in shifted toward the left wall, slide it right until the tab clicks. To open, lift the tab at the left edge and slide the lid left.

Print in PETG or ASA, not PLA: the PSU case runs warm at full load and PLA creeps under the bolted PSU pads.

## Hardware

| Qty | Item | Used for |
|---|---|---|
| 6 | M3 hex nut | 2 perfboard[0] dikavs-half, in pockets under the floor; 2 perfboard[1] dikavs-half, in pockets under the floor; 2 panel[0] c14-fuse-switch flange, inside |
| 2 | M3 x 10 socket head | 2 panel[0] c14-fuse-switch flange, head outside |
| 4 | M3 x 12 socket head | 2 perfboard[0] dikavs-half, from the top; 2 perfboard[1] dikavs-half, from the top |
| 4 | M3 x 6 socket head | 4 psu s-100-5, from under the floor into the PSU (enters 3 mm — do not substitute a longer bolt) |
| 4 | screw, shank <= 4.2 mm, head <= 9 mm | 4 fixing the enclosure (user's choice of screw) |

## Interior

244 × 232 × 55 mm (L × W × H), wall 2.4 mm, floor 3.0 mm.

## Check before printing

Taken from datasheets, not measured on your parts:

- psu s-100-5: from Mean Well S-100F datasheet, case No. 902 (https://www.meanwell.com/Upload/PDF/S-100F/S-100F-SPEC.PDF) — bottom M3 holes 120 mm apart along the length and 80 mm across; nearest hole 62 mm from the terminal end
- jst-sm-3pin: from JST SM connector datasheet, housing drawings p.3 (https://www.jst-mfg.com/product/pdf/eng/eSM.pdf) — both housings pass the 15.6 x 10.2 mm slot (wall exits) and an 18 mm drilled hole (floor exits) without squeezing the latch flaps

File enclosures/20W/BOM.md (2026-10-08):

# 20W — build sheet

GENERATED by `build.py` from `enclosure.yaml`. Do not edit; rebuild instead.

| Base, no lid | Base with parts, no lid | Closed |
|---|---|---|
| base | parts | closed |

Parts are drawn as blocks: grey PSU, green perfboards, black connector bodies; light blue is board clearance, orange is wiring space.

## Printed parts

| File | Print orientation | Size (x × y × z mm) | Supports |
|---|---|---|---|
| `stl/20W-enclosure-base.stl` | floor on the bed | 216.8 × 122.8 × 58.0 | c14-fuse-switch cutout: flat 47.5 mm top (bridge, or support if your slicer wants it) |
| `stl/20W-enclosure-lid.stl` | top face on the bed, lip up | 204.8 × 122.8 × 9.4 | none |

Bed: base leaves 37.2 mm spare on its tightest axis; lid leaves 49.2 mm spare on its tightest axis (256 x 256 bed, 2 mm margin kept).

Both parts fit on one plate: `stl/20W-enclosure-plate.stl` (216.8 × 250.6 mm), already arranged.

The lid needs no hardware: drop it in shifted toward the left wall, slide it right until the tab clicks. To open, lift the tab at the left edge and slide the lid left.

Print in PETG or ASA, not PLA: the PSU case runs warm at full load and PLA creeps under the bolted PSU pads.

## Hardware

| Qty | Item | Used for |
|---|---|---|
| 4 | M3 hex nut | 2 perfboard[0] dikavs-half, in pockets under the floor; 2 panel[0] c14-fuse-switch flange, inside |
| 2 | M3 x 10 socket head | 2 panel[0] c14-fuse-switch flange, head outside |
| 2 | M3 x 12 socket head | 2 perfboard[0] dikavs-half, from the top |
| 2 | M3 x 6 socket head | 2 psu s-20-5, from under the floor into the PSU (enters 3 mm — do not substitute a longer bolt) |
| 3 | screw, shank <= 4.2 mm, head <= 9 mm | 3 fixing the enclosure (user's choice of screw) |

## Interior

184 × 118 × 55 mm (L × W × H), wall 2.4 mm, floor 3.0 mm.

## Drilling the mounting surface

Floor wire exits pass through the board below. Hole centres, measured from the left-wall mounting tab hole (x to the right, y toward the back, looking down on the enclosure):

- x +150.1 mm, y -88.0 mm: drill 18 mm straight through the 20 mm hole, with the enclosure screwed down and empty (the bit clears the plastic by 1 mm all round)
- x +176.1 mm, y -88.0 mm: drill 18 mm straight through the 20 mm hole, with the enclosure screwed down and empty (the bit clears the plastic by 1 mm all round)

## Check before printing

Taken from datasheets, not measured on your parts:

- jst-sm-3pin: from JST SM connector datasheet, housing drawings p.3 (https://www.jst-mfg.com/product/pdf/eng/eSM.pdf) — both housings pass the 15.6 x 10.2 mm slot (wall exits) and an 18 mm drilled hole (floor exits) without squeezing the latch flaps

## Warnings

- psu s-20-5: dimensions NOT verified against the real part

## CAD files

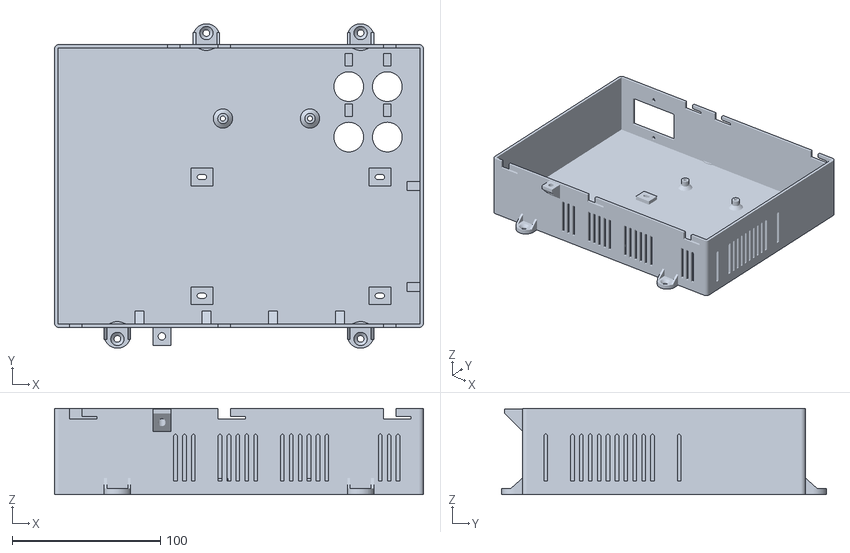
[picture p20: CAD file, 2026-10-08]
enclosures/100W-leds-on-floor/stl/100W-leds-on-floor-enclosure-base.stl
248.8 x 218.8 x 58.0

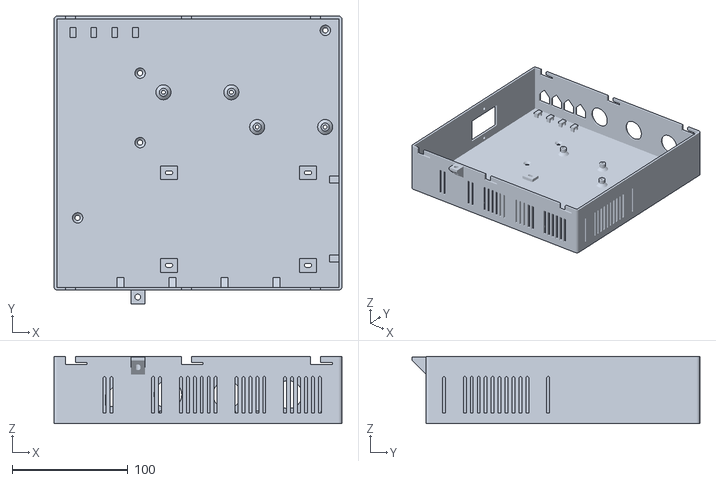
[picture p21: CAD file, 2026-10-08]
enclosures/100W-masterbox/stl/100W-masterbox-enclosure-base.stl
248.8 x 248.8 x 58.0

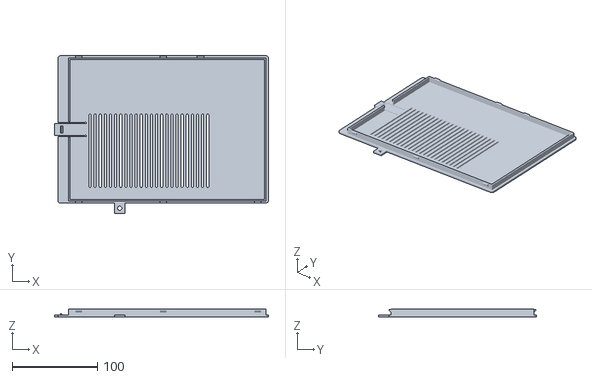
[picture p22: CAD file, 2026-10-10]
enclosures/100W-power-only/stl/100W-power-only-enclosure-lid.stl
250.8 x 184.8 x 9.40

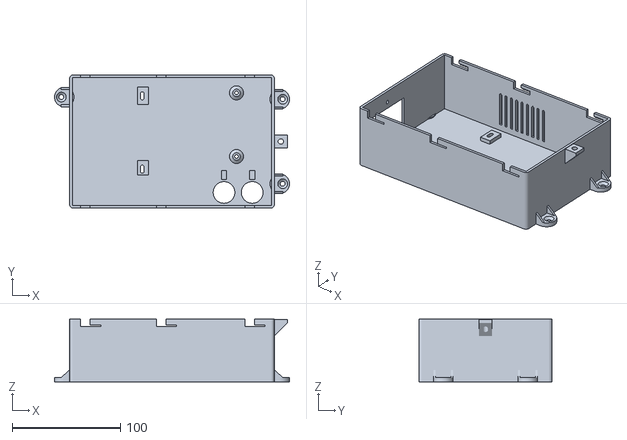
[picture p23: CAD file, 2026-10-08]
enclosures/20W/stl/20W-enclosure-base.stl
216.8 x 122.8 x 58.0

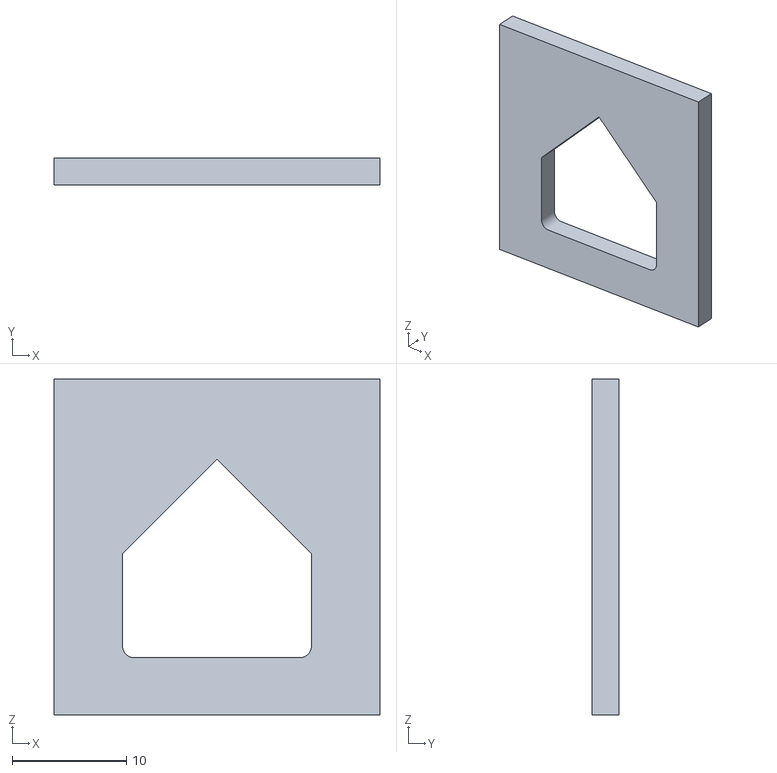
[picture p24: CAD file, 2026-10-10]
test-prints/xt60-f-coupon.stl
28.5 x 2.40 x 29.4

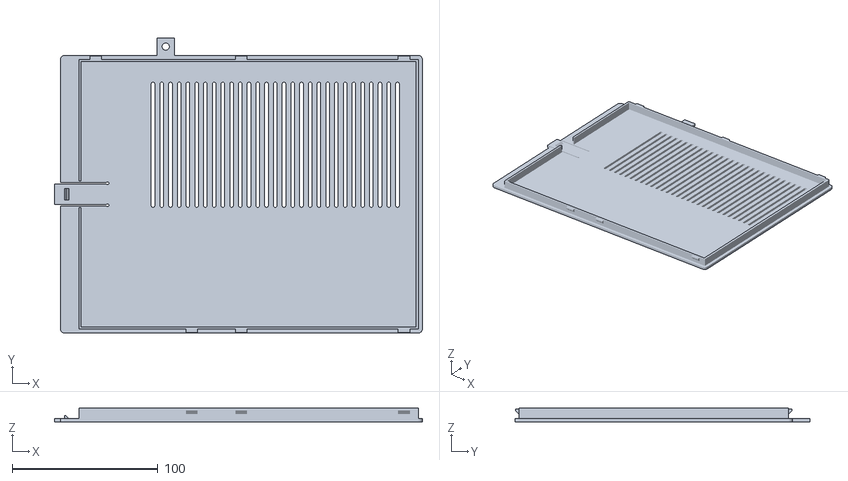
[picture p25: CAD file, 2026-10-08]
enclosures/100W-leds-on-floor/stl/100W-leds-on-floor-enclosure-lid.stl
252.8 x 202.8 x 9.40

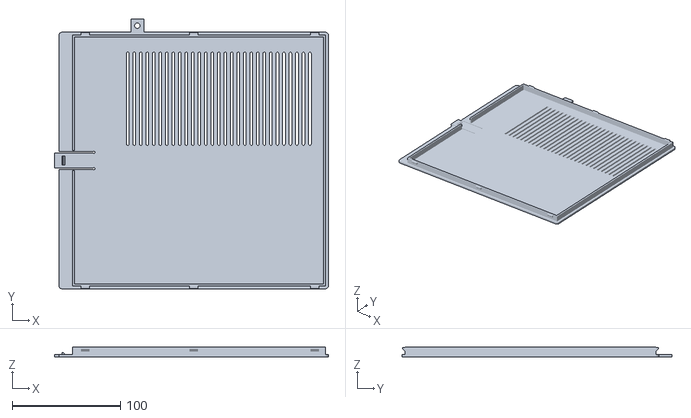
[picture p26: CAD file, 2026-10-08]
enclosures/100W-masterbox/stl/100W-masterbox-enclosure-lid.stl
252.8 x 248.8 x 9.40

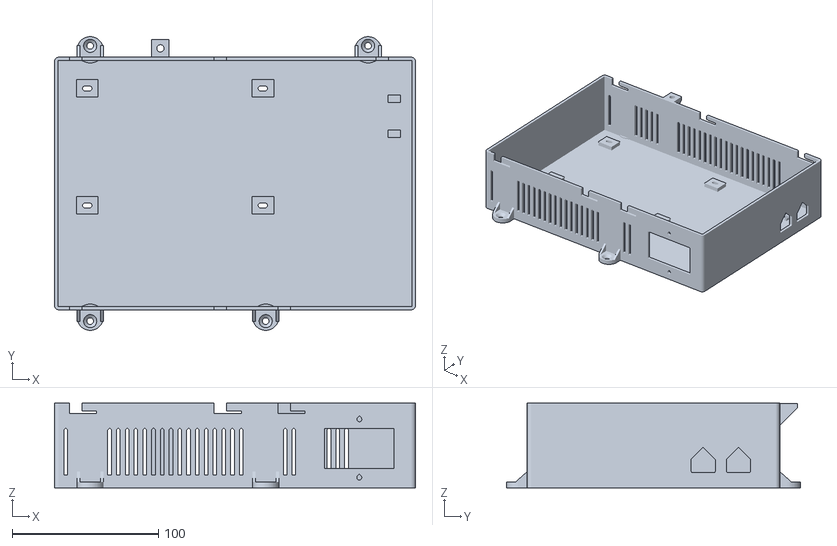
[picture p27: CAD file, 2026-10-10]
enclosures/100W-power-only/stl/100W-power-only-enclosure-base.stl
246.8 x 200.8 x 58.0

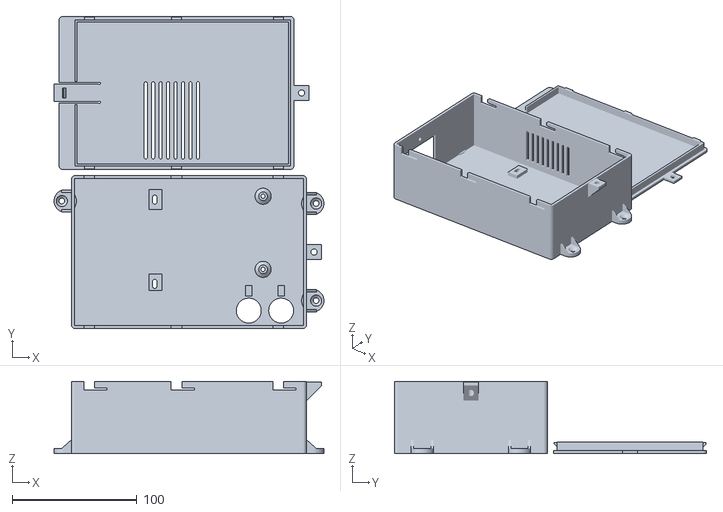
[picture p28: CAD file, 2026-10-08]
enclosures/20W/stl/20W-enclosure-plate.stl
216.8 x 250.6 x 58.0

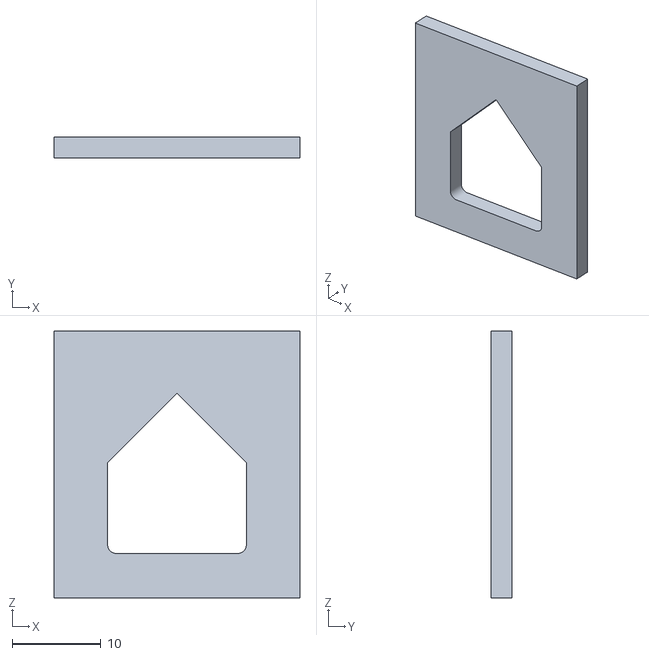
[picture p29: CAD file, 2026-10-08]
test-prints/jst-sm-3pin-coupon.stl
27.6 x 2.40 x 30.0

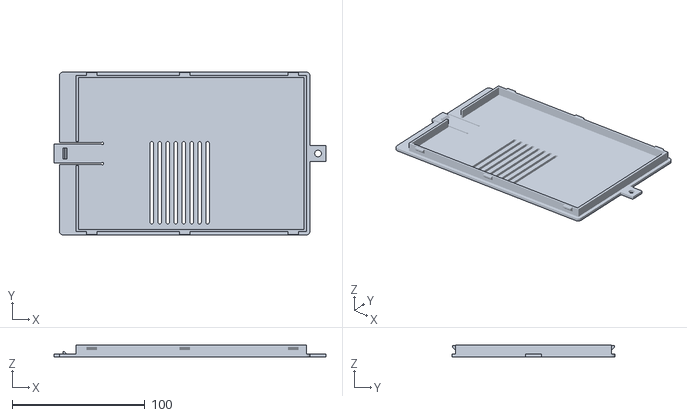
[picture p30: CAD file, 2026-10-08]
enclosures/20W/stl/20W-enclosure-lid.stl
204.8 x 122.8 x 9.40

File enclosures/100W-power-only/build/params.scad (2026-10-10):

// GENERATED by enclosure_builder from enclosures/100W-power-only/enclosure.yaml
// Do not edit: change the YAML and rebuild.

L = 242;
W = 168;
H = 55;
WALL = 2.4;
FLOOR = 3;
OUTER_R = 3;
LAYER = 0.2;
M3_CLEAR = 3.4;
HEAD_CB_D = 6.4;
NUT_POCKET_AF = 5.8;
NUT_POCKET_H = 2.7;
LID_T = 2.4;
LIP_H = 7;
LIP_T = 1.6;
LIP_CLR = 0.3;
TIE_W = 4.5;
TIE_H = 2;
TIE_LEN = 5;
GUIDE_W = 0;
GUIDE_H = 0;
GUIDE_T = 0;
GUIDE_LEN = 0;
LOCK_SLIDE = 10;
TAB_U = 84;
TAB_W = 14;
TAB_LEN = 30;
TAB_SLIT = 1.2;
TAB_PULL = 4;
TOOTH_H = 2;
TOOTH_LEN = 3;
TOOTH_W = 8;
LUG_W = 12;
LUG_REACH = 12;
LUG_HOLE = 5;
LUG_T = 3;
PLATE_LID = [0, 0];

PADS = [
  [132.5, 143, 147.5, 155, 3.5],
  [12.5, 143, 27.5, 155, 3.5],
  [132.5, 63, 147.5, 75, 3.5],
  [12.5, 63, 27.5, 75, 3.5],
];
STANDOFFS = [];
TIE_ANCHORS = [
  [230, 118, 90],
  [230, 142, 90],
];
FLOOR_BOLTS = [
  [140, 149, 3, 3.5, 3.3, 0],
  [20, 149, 3, 3.5, 3.3, 0],
  [140, 69, 3, 3.5, 3.3, 0],
  [20, 69, 3, 3.5, 3.3, 0],
];
FLOOR_MOUNTS = [];
FLOOR_SLOTS = [];
TABS = [
  ["front", 22, 14, 18, 4, 4.5, 9, 8, 2],
  ["front", 142, 14, 18, 4, 4.5, 9, 8, 2],
  ["back", 22, 14, 18, 4, 4.5, 9, 8, 2],
  ["back", 212, 14, 18, 4, 4.5, 9, 8, 2],
];
WALL_RECTS = [
  ["front", 206, 24, 47.5, 27.5, 0.5, 0],
  ["right", 118, 12, 16.5, 9.1, 1, 8.25],
  ["right", 142, 12, 16.5, 9.1, 1, 8.25],
  ["front", 12, 52, 8.6, 8, 0, 0],
  ["front", 154.7, 52, 8.6, 8, 0, 0],
  ["front", 111, 52, 8.6, 8, 0, 0],
  ["back", 12, 52, 8.6, 8, 0, 0],
  ["back", 221.7, 52, 8.6, 8, 0, 0],
  ["back", 111, 52, 8.6, 8, 0, 0],
];
WALL_ROUNDS = [
  ["front", 206, 4.1, 3.4, 0],
  ["front", 206, 43.9, 3.4, 0],
];
WALL_SLOTS = [
  ["back", 5.25, 6, 38, 2.5],
  ["back", 35.25, 6, 38, 2.5],
  ["back", 41.25, 6, 38, 2.5],
  ["back", 47.25, 6, 38, 2.5],
  ["back", 53.25, 6, 38, 2.5],
  ["back", 59.25, 6, 38, 2.5],
  ["back", 83.25, 6, 38, 2.5],
  ["back", 89.25, 6, 38, 2.5],
  ["back", 95.25, 6, 38, 2.5],
  ["back", 101.25, 6, 38, 2.5],
  ["back", 107.25, 6, 38, 2.5],
  ["back", 113.25, 6, 38, 2.5],
  ["back", 119.25, 6, 38, 2.5],
  ["back", 125.25, 6, 38, 2.5],
  ["back", 131.25, 6, 38, 2.5],
  ["back", 137.25, 6, 38, 2.5],
  ["back", 143.25, 6, 38, 2.5],
  ["back", 149.25, 6, 38, 2.5],
  ["back", 155.25, 6, 38, 2.5],
  ["back", 161.25, 6, 38, 2.5],
  ["back", 167.25, 6, 38, 2.5],
  ["back", 173.25, 6, 38, 2.5],
  ["back", 179.25, 6, 38, 2.5],
  ["back", 185.25, 6, 38, 2.5],
  ["back", 191.25, 6, 38, 2.5],
  ["back", 197.25, 6, 38, 2.5],
  ["front", 5.25, 6, 38, 2.5],
  ["front", 35.25, 6, 38, 2.5],
  ["front", 41.25, 6, 38, 2.5],
  ["front", 47.25, 6, 38, 2.5],
  ["front", 53.25, 6, 38, 2.5],
  ["front", 59.25, 6, 38, 2.5],
  ["front", 65.25, 6, 38, 2.5],
  ["front", 71.25, 6, 38, 2.5],
  ["front", 77.25, 6, 38, 2.5],
  ["front", 83.25, 6, 38, 2.5],
  ["front", 89.25, 6, 38, 2.5],
  ["front", 95.25, 6, 38, 2.5],
  ["front", 101.25, 6, 38, 2.5],
  ["front", 107.25, 6, 38, 2.5],
  ["front", 113.25, 6, 38, 2.5],
  ["front", 119.25, 6, 38, 2.5],
  ["front", 125.25, 6, 38, 2.5],
  ["front", 155.25, 6, 38, 2.5],
  ["front", 161.25, 6, 38, 2.5],
];
WALL_POCKETS = [];
LOCK_SLOTS = [
  ["front", 7.7, 26.3, 48, 52],
  ["front", 150.4, 169, 48, 52],
  ["front", 106.7, 125.3, 48, 52],
  ["back", 7.7, 26.3, 48, 52],
  ["back", 217.4, 236, 48, 52],
  ["back", 106.7, 125.3, 48, 52],
];
LID_TONGUES = [
  ["front", 22, 8, 48.5, 51.75, 2],
  ["front", 164.7, 8, 48.5, 51.75, 2],
  ["front", 121, 8, 48.5, 51.75, 2],
  ["back", 22, 8, 48.5, 51.75, 2],
  ["back", 231.7, 8, 48.5, 51.75, 2],
  ["back", 121, 8, 48.5, 51.75, 2],
];
LIP_GAPS = [
  [74.8, 93.2],
];
LID_SLOTS = [
  [35.25, 67.25, 35.25, 150.75, 2.5],
  [41.25, 67.25, 41.25, 150.75, 2.5],
  [47.25, 67.25, 47.25, 150.75, 2.5],
  [53.25, 67.25, 53.25, 150.75, 2.5],
  [59.25, 67.25, 59.25, 150.75, 2.5],
  [65.25, 67.25, 65.25, 150.75, 2.5],
  [71.25, 67.25, 71.25, 150.75, 2.5],
  [77.25, 67.25, 77.25, 150.75, 2.5],
  [83.25, 67.25, 83.25, 150.75, 2.5],
  [89.25, 67.25, 89.25, 150.75, 2.5],
  [95.25, 67.25, 95.25, 150.75, 2.5],
  [101.25, 67.25, 101.25, 150.75, 2.5],
  [107.25, 67.25, 107.25, 150.75, 2.5],
  [113.25, 67.25, 113.25, 150.75, 2.5],
  [119.25, 67.25, 119.25, 150.75, 2.5],
  [125.25, 67.25, 125.25, 150.75, 2.5],
  [131.25, 67.25, 131.25, 150.75, 2.5],
  [137.25, 67.25, 137.25, 150.75, 2.5],
  [143.25, 67.25, 143.25, 150.75, 2.5],
  [149.25, 67.25, 149.25, 150.75, 2.5],
  [155.25, 67.25, 155.25, 150.75, 2.5],
  [161.25, 67.25, 161.25, 150.75, 2.5],
  [167.25, 67.25, 167.25, 150.75, 2.5],
  [173.25, 67.25, 173.25, 150.75, 2.5],
];
LOCK_LUGS = [
  ["back", 70],
];
WIRE_GUIDES = [];
GHOSTS = [
  [202, 60, 0, 40, 98, 48, "Orange", 0.22],
  [3, 60, 3.5, 199, 98, 38, "Silver", 0.9],
  [187, 68, 41.5, 15, 82, 10, "DimGray", 1],
  [182, 0, 10, 48, 35, 28, "Black", 0.85],
  [182, 35, 10, 48, 25, 28, "Orange", 0.22],
  [222, 109.75, 7.45, 20, 16.5, 17.35, "Orange", 0.22],
  [222, 133.75, 7.45, 20, 16.5, 17.35, "Orange", 0.22],
];

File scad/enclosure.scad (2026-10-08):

// Parametric electronics enclosure — geometry only.
//
// This file defines modules and draws nothing by itself. Every dimension comes
// from globals written by the Python builder into enclosures/<name>/build/params.scad;
// the wrapper files next to it `include` this library, then the params, then call
// one of the part modules at the bottom. Layout decisions (where things go, which
// bolt length, vent placement) are made in Python — see docs/enclosure/README.md.
//
// Frame: interior corner at the origin. x = length, y = width, z = up,
// z = 0 is the top of the floor. Walls and floor are outside the interior box
// [0,L] x [0,W] x [0,H]. Units: mm.

$fn = 48;
EPS = 0.01;
STANDOFF_FOOT = 3;   // radial (= vertical) size of the 45° foot under each standoff

// ---------------------------------------------------------------- frames

// Local wall frame: local x runs along the wall (u), local z is up, local y
// points outward through the wall; local y = 0 is the interior face.
module wall_frame(wall, u, z) {
    if (wall == "front")      multmatrix([[1,0,0,u],[0,-1,0,0],[0,0,1,z],[0,0,0,1]]) children();
    else if (wall == "back")  multmatrix([[1,0,0,u],[0,1,0,W],[0,0,1,z],[0,0,0,1]]) children();
    else if (wall == "left")  multmatrix([[0,-1,0,0],[1,0,0,u],[0,0,1,z],[0,0,0,1]]) children();
    else if (wall == "right") multmatrix([[0,1,0,L],[1,0,0,u],[0,0,1,z],[0,0,0,1]]) children();
    else assert(false, str("unknown wall ", wall));
}

// Extrude a 2D (u,z) shape along local y, from y0 (inside) to y1 (outside).
module wall_prism(y0, y1) {
    translate([0, y1, 0]) rotate([90, 0, 0]) linear_extrude(y1 - y0) children();
}

// ---------------------------------------------------------------- 2D helpers

module rrect2d(w, h, r) {
    if (r <= 0) square([w, h], center = true);
    else offset(r = r) square([max(w - 2*r, EPS), max(h - 2*r, EPS)], center = true);
}

// Rectangle w x h (centred) with a 45° pointed roof on top, for openings in
// vertical walls: the roof prints without support or bridging. `rise` is how
// far the roof goes above the rectangle: w/2 is a full point; less leaves a
// flat top (a bridge) of width w - 2*rise, used where a flange hides the roof.
module pointed2d(w, h, r, rise) {
    rrect2d(w, h, r);
    // the roof starts below the rounded corners so no ledge is left under it
    if (rise > 0) polygon([[-w/2, h/2 - r - EPS], [w/2, h/2 - r - EPS], [w/2, h/2],
                           [w/2 - rise, h/2 + rise], [-w/2 + rise, h/2 + rise], [-w/2, h/2]]);
}

// Teardrop for horizontal holes in vertical walls: the 45° point on top prints
// without supports. trunc > 0 cuts the point flat at that height above center;
// trunc < 0 gives a plain circle (a hole whose point would show past its flange).
module teardrop2d(d, trunc = 0) {
  if (trunc < 0) circle(d = d); else {
    r = d / 2;
    tip = r * sqrt(2);
    intersection() {
        hull() {
            circle(d = d);
            translate([0, r * sqrt(2) / 2]) rotate(45) square(r, center = true);
        }
        if (trunc > 0) translate([-d, -d]) square([2*d, d + trunc]);
        else translate([-d, -d]) square([2*d, d + tip + 1]);
    }
  }
}

module stadium2d(len, d) {   // slot along x, center-to-center length `len`
    hull() { translate([-len/2, 0]) circle(d = d); translate([len/2, 0]) circle(d = d); }
}

// Outside footprint shared by base and lid.
module outline2d() {
    translate([-WALL, -WALL]) offset(r = OUTER_R) offset(delta = -OUTER_R)
        square([L + 2*WALL, W + 2*WALL]);
}

// Extrude a 2D (n, z) profile along local x (= u) from u0 to u1, in a wall
// frame. n is the outward distance from the wall's inner face.
module along_wall(u0, u1) {
    translate([u0, 0, 0]) rotate([90, 0, 90]) linear_extrude(u1 - u0) children();
}

// ---------------------------------------------------------------- printability

// Counterbore / nut pocket opened from the underside of a bed-side face, with
// the two sacrificial bridge layers that let it print without supports:
// layer 1 opens a band as wide as the hole across the whole pocket (so the
// first bridges only span the pocket width), layer 2 is the hole itself.
// `pocket` is the 2D pocket outline, `hole_len` / `hole_d` the hole stadium.
module bridged_pocket(z0, depth, hole_len, hole_d) {
    translate([0, 0, z0 - 1]) linear_extrude(depth + 1) children();
    translate([0, 0, z0 + depth - EPS]) linear_extrude(LAYER + EPS)
        intersection() {
            children();
            square([hole_len + hole_d, 100], center = true);
        }
}

// ---------------------------------------------------------------- base parts

// Lid-lock ledges: the slot each lid tongue slides into. Its ceiling slopes 45°
// down toward the outside so it prints without support and matches the tongue.
module lock_cutters() {
    for (k = LOCK_SLOTS) wall_frame(k[0], 0, 0) along_wall(k[1], k[2])
        polygon([[-1, k[3]], [WALL + 1, k[3]], [WALL + 1, k[4] - (WALL + 1)], [-1, k[4] + 1]]);
}

module tab(t) {   // t = [wall, u, len, width, thick, hole_d, csk_d, rib_h, rib_t]
    len = t[2]; w = t[3]; th = t[4]; hd = t[5]; csk = t[6]; rh = t[7]; rt = t[8];
    hole_y = WALL + len * 0.55;
    wall_frame(t[0], t[1], 0) difference() {
        union() {
            // plate, rounded at the free end
            translate([0, 0, -FLOOR]) linear_extrude(th) hull() {
                translate([-w/2, WALL - 1]) square([w, 1]);
                translate([0, WALL + len - w/2]) circle(d = w);
            }
            // side ribs: triangular gussets, printable as 45°-or-shallower slopes
            for (sx = [-1, 1]) translate([sx * (w/2 - rt/2), 0, 0])
                rotate([90, 0, 90]) translate([0, 0, -rt/2]) linear_extrude(rt)
                    polygon([[WALL - 1, -FLOOR + th], [WALL - 1, -FLOOR + th + rh],
                             [WALL + rh, -FLOOR + th]]);
        }
        translate([0, hole_y, -FLOOR - 1]) cylinder(d = hd, h = th + 2);
        if (csk > hd)
            translate([0, hole_y, -FLOOR + th - (csk - hd) / 2 + EPS])
                cylinder(d1 = hd, d2 = csk, h = (csk - hd) / 2);
    }
}

module tie_anchor(a) {   // a = [x, y, angle]: zip-tie tunnel parallel to local x
    // the tunnel has a pointed roof, so the anchor prints without bridging
    translate([a[0], a[1], 0]) rotate(a[2]) difference() {
        translate([-TIE_LEN/2, -TIE_W/2 - 2, -EPS]) cube([TIE_LEN, TIE_W + 4, TIE_H + TIE_W/2 + 1.6]);
        translate([-TIE_LEN/2 - 1, 0, 0]) rotate([90, 0, 90]) linear_extrude(TIE_LEN + 2)
            translate([0, TIE_H/2 - 0.5]) pointed2d(TIE_W, TIE_H + 1, 0, TIE_W/2);
    }
}

// Wire loop for the low-voltage route, leaning on a wall: the wall is one side
// of the tunnel; a leg GUIDE_W out stands on the floor and a 45° roof rises from
// it back into the wall. Prints in place without support; wires run along the wall.
module wire_guide(g) {   // g = [wall, u]
    w = GUIDE_W; t = GUIDE_T; h = GUIDE_H;
    wall_frame(g[0], 0, 0) along_wall(g[1] - GUIDE_LEN / 2, g[1] + GUIDE_LEN / 2) difference() {
        // n < 0 is inside the box; the roof's outer face is t thick, measured square to it
        polygon([[-w - t, 0], [0.5, 0], [0.5, h + w + t * 1.414 + 0.5], [-w - t, h + t * 0.414]]);
        polygon([[-w, -1], [0, -1], [0, h + w], [-w, h]]);
    }
}

// Zip-tie lock lug on the wall: flat top just under the lid's lug, 45° below.
module wall_lug(l) {     // l = [wall, u]
    top = H - 0.4;
    wall_frame(l[0], l[1], 0) difference() {
        along_wall(-LUG_W / 2, LUG_W / 2) polygon([
            [WALL - 1, top], [WALL + LUG_REACH, top], [WALL + LUG_REACH, top - LUG_T],
            [WALL - 1, top - LUG_T - LUG_REACH - 1]]);
        translate([0, WALL + LUG_REACH / 2, top - LUG_T - LUG_REACH - 2])
            cylinder(d = LUG_HOLE, h = LUG_T + LUG_REACH + 4);
    }
}

module floor_additions() {
    for (p = PADS) translate([p[0], p[1], -EPS]) cube([p[2] - p[0], p[3] - p[1], p[4] + EPS]);
    // Standoffs get a 45° foot: the nut pocket below takes almost the whole
    // floor thickness, so the foot is what ties the standoff to the floor.
    for (s = STANDOFFS) translate([s[0], s[1], -EPS]) {
        cylinder(d = s[2], h = s[3] + EPS);
        cylinder(d1 = s[2] + 2 * STANDOFF_FOOT, d2 = s[2], h = min(STANDOFF_FOOT, s[3]) + EPS);
    }
    for (a = TIE_ANCHORS) tie_anchor(a);
    for (g = WIRE_GUIDES) wire_guide(g);
}
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

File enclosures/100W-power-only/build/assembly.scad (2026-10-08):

// GENERATED — open in OpenSCAD to inspect. Rebuild with build.py.
include <../../../scad/enclosure.scad>
include <params.scad>
part_assembly();

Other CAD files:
enclosures/100W-rj45/stl/100W-rj45-enclosure-base.stl
enclosures/100W/stl/100W-enclosure-base.stl
enclosures/100W-power-only/build/base.scad
enclosures/100W-power-only/build/interior.scad
enclosures/100W-power-only/build/lid.scad
enclosures/100W-power-only/build/plate.scad
test-prints/jst-sm-3pin-coupon.scad
test-prints/xt60-f-coupon.scad

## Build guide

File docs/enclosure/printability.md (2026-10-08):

# Printability

Path: [docs](../README.md) › [enclosure](README.md) › **printability**
Parent: [README.md](README.md)
**Code:** `scad/enclosure.scad` (`pointed2d`, `teardrop2d`, `bridged_pocket`, `part_base_print`, `part_lid_print`), `enclosure_builder/layout.py` (`_cutout`, roof heights)
**Covers:** what makes every feature print without supports, in the fixed orientations.

## What it does

- **Base**: floor on the bed. Every opening in a wall has a 45° pointed top (`pointed2d`,
  `teardrop2d`): vent slats, wire holes, connector slots, zip-tie tunnels. Panel-part cutouts
  (C14, RJ45) get as much point as their flange hides and the wall height allows. Pockets opened from the underside (PSU bolt heads, perfboard nuts) use
  sacrificial bridge layers. Lid-lock slots have a 45° ceiling; their entry notches are open at
  the top.
- **Lid**: top face on the bed; the lip, the tooth and every hole are vertical; the tongues'
  undersides (their in-use tops) are 45°.

## Decisions

### Sacrificial bridge layers over bed-side pockets (`bridged_pocket`)

**Why.** A counterbore or nut pocket opened from the bed side has a ceiling with a smaller hole
in it — a ring that would otherwise be printed in mid-air. Layer 1 above the pocket leaves a band
as wide as the hole open across the whole pocket, so its material bridges only the short way
between pocket walls; layer 2 then bridges the band, leaving the hole. One layer each, so
`printer.layer_h` must equal the slicer's layer height.
**Rejected.** Support material inside pockets: hard to remove from a 6 mm counterbore, and the
owner wants minimal supports. A 0.2 mm "drill-through" skin: needs a post-print step.
**Constrains.** Heads and nuts seat one layer above the pocket depth; `place_psu` and
`place_perfboards` include `layer_h` in their height maths.

### Pointed (almond) tops instead of bridges

**Why.** Owner request (2026-10-07): openings that can be shaped to print without support or
bridging should be. A 45° roof is self-supporting; a flat top is a bridge that sags and strings.
**Rule.** Openings nothing covers (vent slats, wire holes, JST slots, tie-anchor tunnels) get a
full point, accepting the extra height (half the opening's width). Panel-part cutouts get a full
point only if all of it stays hidden behind the flange (1 mm inside its edge) and below the wall
under the lid lip; otherwise they keep their plain shape (rectangle, circle) and print with a
bridge or a little support. Never a partial point.
**Why no partial points (owner, 2026-10-08).** Avoiding support only pays when it removes it
altogether; once a support or bridge is there, 10 mm vs 15 mm makes little difference, while a
truncated point can show past the flange as a visible notch. In 100W both the C14
(lying down) and the RJ45 are plain for this reason.
Plain cutouts are listed in the BOM's Supports column.
**Changed 2026-10-08:** previously panel cutouts got as much point as fitted (a trapezoid on the
C14, a truncated teardrop on the RJ45).
**Changed 2026-10-07:** previously vent slots and connector slots had flat (bridged) tops and
round holes ≥ 10 mm were truncated at 1.08 r for looks. Changed at the owner's request: fewer
bridges beat a slightly taller opening.
- **45° maximum slope everywhere else** (tab ribs, standoff feet, countersinks open upward,
  lid-lock ledges and tongues, the tooth ramp, wire loops, the zip-tie lug's underside).
- **Retaining faces that must be horizontal are avoided altogether.** In this pair of print
  orientations any horizontal retaining face is an overhang on one of the two parts, so the lid
  lock uses parallel 45° faces (see [lid_closure.md](lid_closure.md)).

## Gotchas

- Slicer "detect bridging perimeters" should be on; nothing here needs supports, so supports
  should be off — auto supports would fill the bed-side pockets.

## Related

- [psu_mount.md](psu_mount.md), [perfboard_mount.md](perfboard_mount.md) — users of `bridged_pocket`.
- [wall_openings.md](wall_openings.md) — users of `teardrop2d`.
- [../parameters/defaults.md](../parameters/defaults.md) — `printer.layer_h`.

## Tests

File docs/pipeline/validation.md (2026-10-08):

# Validation

Path: [docs](../README.md) › [pipeline](README.md) › **validation**
Parent: [README.md](README.md)
**Code:** `enclosure_builder/validate.py`
**Covers:** the checks that stop a bad layout from producing STLs.

## What it does

1. Keep-outs lie inside the interior and below the lid lip.
2. Keep-outs do not overlap (except wiring/anchor combinations — see
   [layout_model.md](layout_model.md)).
3. Wall through-cuts stay `feature_margin` from wall ends, the floor and the lid lip (the lid-lock
   notches are exempt: they are meant to reach the top); outside-only
   footprints stay within the wall's height; features of different parts on one wall keep
   `feature_margin` apart (two outside-only footprints may touch). Panel-part flange nuts use a
   0.5 mm floor/lip clearance instead (`WallFeat.edge_margin`).
4. Floor mounting holes and floor wire exits are not under any solid keep-out; floor wire exits
   also keep `feature_margin` from the walls (reason in
   [../enclosure/wall_openings.md](../enclosure/wall_openings.md)).
5. Mains panel parts are on the PSU's AC side; perfboards and low-voltage panel parts on its DC
   side, or on the AC side ≥ `lv_gap` from the mains region when `lv_route: far_end` (rules in
   [../enclosure/README.md](../enclosure/README.md) and [../enclosure/wire_routing.md](../enclosure/wire_routing.md)).
6. Base and lid footprints fit the bed minus `printer.bed_margin`, in either orientation; the
   spare millimetres are written to the BOM. The base also keeps `printer.support_margin` of bed
   outside each wall whose holes need slicer supports (C14 cutout, plain round holes), so tree
   supports have somewhere to stand. Default 0; the 100W-masterbox uses 5 (owner, 2026-10-08).

## Decisions

- **Errors, not auto-fixes.** Moving a part is a design decision for the owner or the agent;
  the validator only says what collides and by how much.
- **Two outside-only footprints may touch** (e.g. a tab beside a flange): they are both solid
  plastic that merges, while a through-cut must keep material around it.
- **Bed fit keeps a 2 mm margin and reports what is left**, because the owner expected the
  layout constraints to push against the bed and wants to see how close it is.
- **Bed fit includes tabs and the lid's finger pull**, the parts most often forgotten when
  sizing a box.
- **Unverified components are warnings, datasheet ones are "checks", neither is an error.** A
  test-fit print is often how a guess gets verified; refusing to build would prevent it.

## Gotchas

- Validation knows nothing about wire routing or bend radii beyond the keep-out boxes; mains
  separation from low voltage is a layout choice recorded per enclosure.

## Related

- [../enclosure/lid_closure.md](../enclosure/lid_closure.md) — the lip limit.
- [../parameters/enclosure_definition.md](../parameters/enclosure_definition.md) — the file being checked.

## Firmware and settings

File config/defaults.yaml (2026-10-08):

# Defaults for every enclosure. An enclosure's enclosure.yaml is deep-merged on
# top of this file, so any key here can be overridden per enclosure.
# Units: mm. Reasons for these values: docs/parameters/defaults.md

printer:
  bed: [256, 256]        # X/Y print area (Bambu Lab A1); the build fails if a part does not fit
  bed_margin: 2          # total mm kept free per axis so the part is not right at the bed edge
  support_margin: 0      # bed room kept outside each wall whose holes need slicer supports
  layer_h: 0.2           # height of the sacrificial bridge layer in bed-side pockets

box:
  wall: 2.4              # 6 perimeters of a 0.4 nozzle
  floor: 3.0
  outer_radius: 3.0      # vertical outer edges
  feature_margin: 2.0    # min material between neighbouring wall features

hardware:
  # Every bolt in the enclosure is M3 socket head (ISO 4762 / DIN 912).
  m3:
    clear_d: 3.4
    head_d: 5.5
    head_h: 3.0
    head_cb_d: 6.4       # counterbore for the head
    head_recess: 0.3     # how far a head sits below the surface it is recessed into
    nut_af: 5.5          # across flats
    nut_h: 2.4
    nut_pocket_clearance: 0.3   # hex pocket in the floor (nut dropped in from below)
    lengths: [5, 6, 8, 10, 12, 14, 16, 18, 20, 25, 30]

lid:
  # Drop-and-slide lid, no hardware. Reasons: docs/enclosure/lid_closure.md
  thickness: 2.4
  lip_h: 7.0             # lip height; also carries the lock tongues
  lip_t: 1.6
  lip_clearance: 0.3
  slide: 10              # the lid drops in this far left of closed, then slides right to lock
  tongues: auto          # u positions on the front/back walls, or auto (ends + middle)
  tongue_w: 8            # along the wall
  tongue_reach: 2.0      # tongue tip, measured outward from the wall's inner face
  tongue_clearance: 0.3
  rim: 3.0               # wall left above the lock slot, at the inner face
  tab_u: null            # detent tab centre along the left wall (null = middle)
  tab_w: 14
  tab_len: 30            # flexing length; ~1 % strain when lifted to clear the tooth
  tab_slit: 1.2
  tab_pull: 4            # finger pull sticking out past the left wall
  tooth_h: 2.0
  tooth_len: 3.0
  tooth_w: 8
  lock_lug: null         # {wall: front|back, u: ...} adds a zip-tie lock
  lug_w: 12              # along the wall
  lug_reach: 12          # out from the wall's outer face
  lug_hole: 5.0          # takes zip ties up to 4.8 mm wide
  lug_t: 3.0             # wall lug thickness at its tip (45° underneath)

wire_guides:             # printed loops for psu.lv_route, leaning on a wall
  w: 7                   # tunnel width, out from the wall
  h: 8                   # tunnel height before the 45° roof starts
  t: 1.6                 # leg and roof thickness
  len: 6                 # along the wires
  spacing: 45
  fits: null             # optional [a, b]: a connector cross-section that must pass through
  fit_clearance: 0.8

perfboard:
  min_standoff: 6        # gap under the board for solder joints and wires

vents:
  slot_w: 2.5            # < 12.5 mm finger probe; small enough to stop most debris
  pitch: 6.0
  lid_slot_w: 2.5
  lid_pitch: 6.0
  lid_margin: 4.0        # keep lid slots this far inside the lid lip
  lid_over_psu: true     # slot the lid above the PSU (not above its terminals)
  walls: []              # wall slot regions, set per enclosure

wire_tie:                # printed zip-tie anchor next to a wire hole
  anchor_distance: 12    # anchor centre, measured in from the wall
  w: 4.5                 # tunnel width (fits 2.5-4 mm ties)
  h: 2.0                 # tunnel height
  len: 5.0               # anchor length along the wall

mounting:
  style: tabs            # tabs | floor
  screw_d: 4.5           # through-hole for the screw that fixes the enclosure in place
  head_d: 9.0            # countersink diameter; set equal to screw_d for a plain hole
  tab_len: 14
  tab_w: 18
  tab_t: 4
  rib_h: 8
  rib_t: 2
  tabs: []
  floor_holes: []

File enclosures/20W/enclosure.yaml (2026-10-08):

# 20W — S-20-5 PSU, one perfboard, C14 inlet, two JST-SM LED exits.
# Docs: docs/enclosures/20w.md
#
# Frame: interior corner at the origin, x = length (left -> right wall),
# y = width (front -> back wall), z = up from the floor's top surface.
# Wall features use (wall, u, z): u is measured along the wall from the end
# with the smaller x (front/back walls) or smaller y (left/right walls).
#
# Layout (owner, 2026-10-08), left to right on one line: inlet in the left
# wall, PSU with its terminals ("wires") facing the front wall, perfboard
# parallel to the PSU. Facing the terminals from the front, AC is on the left
# (toward the inlet) and DC on the right (toward the perfboard): no crossing.

name: 20W

box:
  # height: set by the inlet lying down — its two flange nuts, 40 mm apart one
  # above the other, must clear the floor and the lid lip (PSU alone needs ~45)
  # width 118 = 28 terminal space + 87 PSU + 3: small enough for base and lid
  # to share one A1 plate
  inner: [184, 118, 55]

lid:
  lock_lug: {wall: right, u: 59}   # zip-tie lock on the short wall, so the lid stays narrow

psu:
  part: s-20-5
  at: [60, 28]           # 28 mm terminal space to the front wall; inlet + its wires to the left
  terminals: front
  override:
    terminal_clearance: 28   # 2 mm less than the library's 30, for the one-plate fit

perfboards:
  - part: dikavs-half
    at: [124, 34]        # parallel to the PSU (long side along y); 3 mm from the back wall like the PSU, leaving 34 mm in front for the round LED holes
    rotate: 90

panel_parts:
  - part: c14-fuse-switch
    wall: left
    u: 36                # toward the front: its wires turn straight into the terminal space
    z: 24                # lower nut clears the floor, upper nut clears the lid lip
    rotate: 90           # lying down: 50 mm tall instead of 69

wire_holes:
  # LED strips: JST-SM pigtails pass down through the floor, in the strip
  # between the perfboard and the front wall. The holes are round (20 mm) so
  # the board under the box can be drilled (18 mm) straight through them; the
  # zip-tie anchor sits between each hole and the perfboard, on the wires' path.
  - {part: jst-sm-3pin, wall: floor, at: [140, 12], anchor_at: [0, 16]}
  - {part: jst-sm-3pin, wall: floor, at: [166, 12], anchor_at: [0, 16]}

vents:
  lid_over_psu: true
  walls:
    - {wall: back, u: [62, 117], z: [6, 38]}     # behind the PSU's far end

mounting:
  # Tabs on the short walls: the box is short enough that they cost nothing,
  # while tabs on the long walls would make base + lid too deep for one plate.
  style: tabs
  tabs:
    - {wall: left, u: 100}     # clear of the inlet's flange
    - {wall: right, u: 20}
    - {wall: right, u: 98}

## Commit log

2026-10-08 Parametric 3D-printed electronics enclosures
    YAML measurements -> Python layout and validation -> OpenSCAD -> STLs.
    - Enclosures: 20W (S-20-5), 100W, 100W-rj45 and 100W-masterbox (S-100-5),
    each with STLs in print orientation, previews and a BOM.
    - Component library: S-100-5 and S-20-5 supplies, DIKAVS perfboard, C14
    inlet, RJ45 bulkhead, JST SM 3-pin pass-through.
    - Tool-free drop-and-slide lid with zip-tie lock; M3 only, no inserts;
    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
    [100W-enclosure-base.stl, 100W-enclosure-lid.stl, 100W-masterbox-enclosure-base.stl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]
2026-10-08 Show base, parts and closed renders in every BOM and the README
    Each generated BOM.md now opens with the three key previews (empty base,
    base with parts, closed enclosure); the README shows them for all four
    enclosures.
2026-10-08 Add 100W-leds-on-floor; round floor LED holes drilled through
    Floor wire exits now use the passthrough part's round hole (JST SM: 20 mm
    printed, 18 mm drill), so the mounting board can be drilled straight
    through them without touching the plastic.
    - 100W-leds-on-floor: 100W without RJ45, four LED holes in a 2x2 grid in
    the floor right of the perfboard.
    - 20W: round floor holes; perfboard moved to the back wall to make room.
    - BOM drilling guide gives the drill to use through each round hole.
    - Validator: floor exits keep feature_margin from the walls.
    - Docs updated, including the reversed "100W never uses the floor" rule.
    [100W-leds-on-floor-enclosure-base.stl, 100W-leds-on-floor-enclosure-lid.stl, 20W-enclosure-base.stl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]
2026-10-08 100W-masterbox: 6 MAX485 modules, two per RJ45 (was 8)
    Owner correction. No geometry change: the module count never set a dimension.
    [enclosure.yaml]
2026-10-10 Add 100W-power-only: S-100-5, C14, two XT60 pigtail outputs
    PSU along the length with its terminals to the right wall; the XT60
    female pigtails leave through the right wall straight in front of the
    -V/+V terminals so their 10 cm leads reach without extension. The C14
    lies in the front wall, sharing it with the lid-lock slots, so only the
    front and back walls need supports. No perfboard.
    New passthrough part xt60-f (16.5 x 9.1 slot from the Amass XT60-F
    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
    [100W-power-only-enclosure-base.stl, 100W-power-only-enclosure-lid.stl, assembly.scad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]
2026-10-10 RJ45 bulkhead hole 25 mm (was 24): printed hole too small
    The 24.0 cut left 0.3 mm per side on the 23.4 mm thread; FDM shrinkage and
    the sagging top of the plain round hole closed it, and the coupler only went
    in after a Dremel pass. 0.8 mm per side; loose is harmless as the coupler is
    clamped by its own nut. Rebuilt 100W-rj45 and 100W-masterbox.
2026-10-10 100W-power-only: centre the XT60 slots on the DC terminals
    Read the S-100F drawing at high zoom: terminal 1 is 18.1 mm from the
    AC-side edge with a 9.5 mm pitch, so -V is at y 106.6/116.1 and +V at
    125.6/135.1. The slots move from u 118/142 (estimated block position) to
    109/133; each XT60 still takes one -V and one +V. Terminal centres are
    recorded in the s-100-5 component file.
2026-10-25 Add masterbox-4-perfboards: two board pairs, RJ45s over the back boards
    Extends 100W-masterbox for 7 MAX485s + ESP32 on four DIKAVS boards: two
    pairs side by side behind the PSU, boards in a pair 1.68 mm apart so the
    2.54 mm pitch continues across the gap. RJ45s raised to z 25 and pushed
    toward the right wall, reaching over the back boards' rear strip; the
    back-right floor screw moves behind the boards.
    Perfboards are now a solid board keep-out plus a `components` keep-out
    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
